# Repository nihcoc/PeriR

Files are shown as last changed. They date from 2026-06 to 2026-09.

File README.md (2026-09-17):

# PeriR
> Under Development!

---

## Abstract

A custom Software Defined Radio (SDR) HAT built around the Xilinx Artix-7 XC7A50T FPGA and Analog Devices AD9364 RF transceiver.
This project is inspired by the [FreeSRP](http://electronics.kitchen/misc/freesrp/) open-source SDR by Lukas Lao Beyer and design references from the  <a href="https://wiki.analog.com/resources/eval/user-guides/ad-fmcomms4-ebz">FMCOMMS4</a>.

The goal is a powerful, Linux-capable SDR transceiver with a compact form factor and eventually, a handheld device like the HackRF Portapack.

---

## Key Specifications

| Feature | Detail |
|---|---|
| **SoM** | Compute Module 4 |
| **FPGA** | Xilinx Artix-7 XC7A50T FPGA |
| **RF Transceiver** | Analog Devices AD9364 |
| **Frequency Range** | 70 MHz – 6.0 GHz |
| **Bandwidth** | 200 kHz – 56 MHz |
| **Interfaces** | PCIe 2.0 x1, USB2.0 |
---

## Hardware Design

Read my <a href="https://github.com/nihcoc/PeriR/blob/main/perir-journal.md">Hardware Journal and 120 Hours of footage of my entire design process</a> here!

### RF
- **Balun:** TCM1-63AX+ wideband RF transformer (10MHz to 6GHz)
- **Clock:** 40 MHz TCXO
- **Power:** ADP1754ACPZ-1.3-R7 (Recommended by AD)
- **TX Power Amp:** PGA-102 (dedicated clean 3.3V supply)
- **Trace:** Output traces are 50Ω controlled for the JLC06161H-3313A stack-up, Co-planar and no solder mask

### Power Architecture

| Rail | IC | Current | 
|---|---|---|
| 1.0V | TPS62130A | 3A | 
| 1.8V | TPS62130A | 3A | 
| 3.3V | TPS62130A | 3A | 
| 2.5V | TPS62130A | 3A | 
| 1.2V | TPS62130A | 3A | 
| 1.3V | ADP1754ACPZ-1.3-R7 | 3A |
| 5V | External connector | ~ 8A  |

> Sequencing is managed using EN (Enable) and PG (Power Good) pins chained between power ICs. See Pg8 on ([DS181](https://docs.amd.com/v/u/en-US/ds181_Artix_7_Data_Sheet))

### Interfaces
**CM4 INTERFACES**
| CM4 Interface | Notes |
|---|---|
| **HDMI** | Length matched, 100Ω  Differential|
| **USB** | Length matched, 100Ω  Differential|
| **DSI** | Length matched, 100Ω  Differential |
| **SD Card** |  Length matched, 50Ω |
| **PCIe 2.0 x1** | ±1ps Length matched , 90Ω Differential (See ([Pg7 2.3](https://pip-assets.raspberrypi.com/categories/634-raspberry-pi-compute-module-4/documents/RP-008168-DS-4-cm4-datasheet.pdf)) ) |
| **DEBUG LEDS** | Blue leds for debug/status |

> Impedance controlled according to the JLC06161H-3313A stack-up using the [JLCPCB impedence calculator](https://jlcpcb.com/pcb-impedance-calculator)

**FPGA INTERFACES**
| FPGA Interface | Notes |
|---|---|
| **USB 2.0** | Routed for the asynchronous 245 FIFO mode on FT2232HL |
| **PCIe 2.0 x1** | GTP transceivers are only supported on a few Artix-7 chips such as the CSG-325 |
| **JTAG** | Bank_0 |
| **Transceiver Digital Interface** | Routing configured for the DUAL PORT FULL DUPLEX MODE using the LVDS signaling standard. LVDS mode is supported on the XC7A50T-CSG325 but only when VCCO_x is supplied with 2.5V|
| **DEBUG LEDS** | Blue leds for debug/status |

> Impedance for the layer 3 LVDS signals is not 100Ω because I mistakenly used the JLC06161H-3313E stackup to calculate the impedance for this layer. It's not ideal, but the traces are only around 3 cm long, so the impact of the mismatch should be relatively small. I can validate the interface at a lower data rate and use diagnostics and timing analysis to check the signal margin. I'll fix the impedance mismatch properly in V2.

---

###  Key Datasheets

| Part | Source |
|---|---|
| **XC7A50T** | [UG470 CONFIG/FLASH](https://docs.amd.com/v/u/en-US/ug470_7Series_Config) |
| **XC7A50T** | [DS181 POWER](https://docs.amd.com/v/u/en-US/ds181_Artix_7_Data_Sheet) |
| **XC7A50T** | [UG483 LAYOUT/CAPS](https://docs.amd.com/v/u/en-US/ug483_7Series_PCB) |
| **XC7A50T** | [UG482 GTP(PCIe)](https://docs.amd.com/v/u/en-US/ug482_7Series_GTP_Transceivers) |
| **XC7A50T** | [UG472 CLOCKING ](https://docs.amd.com/v/u/en-US/ug472_7Series_Clocking) |
| **AD9364** | [UG673 Main Reference](https://www.analog.com/media/en/technical-documentation/data-sheets/AD9364.pdf) |
| **AD9364** | [Overview](https://www.scribd.com/document/271013063/AD9364-Reference-Manual-UG-673) |
| **FT2232H** | [Main Reference](https://ftdichip.com/wp-content/uploads/2024/09/DS_FT2232H.pdf) |
| **Compute Module 4** | [Main Reference](https://pip-assets.raspberrypi.com/categories/634-raspberry-pi-compute-module-4/documents/RP-008168-DS-4-cm4-datasheet.pdf)|
| **TPS62130** | [Main Reference](https://www.ti.com/lit/gpn/TPS62130A)|
| **ADP1754ACPZ-1.3-R7** | [Main Reference](https://www.analog.com/media/en/technical-documentation/data-sheets/ADP1754_1755.pdf)|
| **NCP700BSN33T1G** | [Main Reference](https://www.onsemi.com/pdf/datasheet/ncp700b-d.pdf)|
| **ADM7160AUJZ-1.8-R7** | [Main Reference](https://www.analog.com/media/en/technical-documentation/data-sheets/ADM7160.pdf)|
| **TCM1-63AX+** | [Main Reference](https://www.minicircuits.com/pdfs/TCM1-63AX+.pdf)|
| **PGA-102+** | [Main Reference](https://www.minicircuits.com/pdfs/PGA-102+.pdf)|

---

## Software

CM4 - FPGA - AD9364 software/digital design interface is in development.

**General Software**

- **OS:** [Kuiper Linux](https://wiki.analog.com/resources/tools-software/linux-software/kuiper-linux) by Analog Devices
- **Reference HDL:** ([https://github.com/analogdevicesinc/hdl/blob/main/library/axi_ad9361/axi_ad9361.v](https://github.com/analogdevicesinc/hdl/blob/main/library/axi_ad9361/axi_ad9361.v))

---

## Layers



*Layer 1(Top)*



*Layer 2(GND)*



*Layer 3*



*Layer 4(Power)*
> IDK how I didn't notice but my power planes look hideous and probably subpar with those sharp edges and uneven clearances. Gotta fix this in V2.



*Layer 5(GND/LOW Speed Signals)*



*Layer 6(Bottom)*

---

## Bill of Materials

 Total = ~$485(excl. shipping)

| # | LCSC# | MPN | Manufacturer | Package | Board Ref | Description | Qty | MOQ | Unit Price ($) | Ext. Price ($) | Product Link |
|---|---|-----|---|---|---|---|-----|-----|---|---|---|
| 1 | C444946 | AD9364BBCZ | ADI | BGA-144 | U4 | -122dBm 70MHz~6GHz 1.2V~3.3V BGA-144 RF Transceiver ICs RoHS | 1 | 1 | 96.5166 | 96.52 | [Link](https://www.lcsc.com/product-detail/C444946.html) |
| 2 | C5199907 | SMA-J-P-H-ST-EM1 | Samtec | SMD | J12, J13, J14 | Connector Receptacle SMA 50Ω | 3 | 1 | 4.8959 | 14.69 | [Link](https://www.lcsc.com/product-detail/C5199907.html) |
| 3 | C337502 | TPS62130ARGTR | TI | QFN-16-EP(3x3) | U7, U8, U9, U10, U12 | 2.5MHz Step-down type Adjustable 900mV~6V 3A QFN-16-EP(3x3) Voltage Regulators - DC DC Switching Regulators RoHS | 5 | 1 | 0.7910 | 3.96 | [Link](https://www.lcsc.com/product-detail/C337502.html) |
| 4 | C9002 | X322512MSB4SI | YXC Crystal Oscillators | SMD3225-4P | Y4 | Crystal 12MHz ±10ppm 20pF SMD3225-4P | 5 | 5 | 0.1012 | 0.51 | [Link](https://www.lcsc.com/product-detail/C9002.html) |
| 5 | C55061480 | PUBFA-R23A-003 | YUWENFA | Through Hole | J7 | USB 2.0 Through Hole USB, DVI, HDMI Connector Adapters RoHS | 5 | 5 | 0.0583 | 0.29 | [Link](https://www.lcsc.com/product-detail/C55061480.html) |
| 6 | C720616 | HDMI-001S | XUNPU | SMD | J5 | HDMI-A Receptacle Connector 19 Position Surface Mount, Right Angle | 5 | 5 | 0.2424 | 1.21 | [Link](https://www.lcsc.com/product-detail/C720616.html) |
| 7 | C2765186 | TYPE-C 16PIN 2MD(073) | SHOU HAN | SMD | J9 | USB-C (USB TYPE-C) Receptacle Connector 16 Position Surface Mount, Right Angle | 20 | 20 | 0.0707 | 1.41 | [Link](https://www.lcsc.com/product-detail/C2765186.html) |
| 8 | C7529389 | TF-CARD H1.8 | SHOU HAN | SMD | J2 | Micro SD card (TF card) Connector and Ejector Push-Push Surface Mount | 10 | 10 | 0.0608 | 0.61 | [Link](https://www.lcsc.com/product-detail/C7529389.html) |
| 9 | C720557 | DC-005-A200 | XUNPU | Through Hole | J10 | Power Barrel Connector Jack 2mm ID 6.4mm OD Through Hole, Right Angle | 5 | 5 | 0.1294 | 0.65 | [Link](https://www.lcsc.com/product-detail/C720557.html) |
| 10 | C502010 | MLJ1608WR33JT000 | TDK | 0603 | L13, L14 | 500mA 330nH ±5% 320mΩ 650mA Multilayer inductor 0603 Fixed Inductors RoHS | 10 | 10 | 0.0744 | 0.74 | [Link](https://www.lcsc.com/product-detail/C502010.html) |
| 11 | C85837 | BLM21AG601SN1D | muRata | 0805 | FB4 | 600Ω@100MHz 1 Line Ferrite Bead 0805 700mA 210mΩ | 20 | 20 | 0.0618 | 1.24 | [Link](https://www.lcsc.com/product-detail/C85837.html) |
| 12 | C424649 | DF40HC(3.0)-100DS-0.4V(51) | HRS | SMD, P=0.4mm | H1 | High-Density Board-to-Board Connector 100-pos 0.4mm pitch | 2 | 1 | 1.8918 | 3.78 | [Link](https://www.lcsc.com/product-detail/C424649.html) |
| 13 | C25120 | 0402WGF499JTCE | UNI-ROYAL | 0402 | R33 | 49.9Ω ±1% 62.5mW 0402 Thick Film Resistor | 100 | 100 | 0.0011 | 0.11 | [Link](https://www.lcsc.com/product-detail/C25120.html) |
| 14 | C2906901 | FRC0402J1R0 TS | FOJAN | 0402 | R31, R32 | 1Ω ±5% 62.5mW 0402 Thick Film Resistor | 100 | 100 | 0.0016 | 0.16 | [Link](https://www.lcsc.com/product-detail/C2906901.html) |
| 15 | C852856 | RT0402BRD075K1L | YAGEO | 0402 | R27, R28 | 5.1kΩ 62.5mW 50V Thin Film Resistor ±25ppm/℃ ±0.1% 0402 Chip Resistor - Surface Mount RoHS | 50 | 50 | 0.0216 | 1.08 | [Link](https://www.lcsc.com/product-detail/C852856.html) |
| 16 | C2909316 | FRC0402F1202TS | FOJAN | 0402 | R25 | 12kΩ ±1% 62.5mW 0402 Thick Film Resistor | 100 | 100 | 0.0014 | 0.14 | [Link](https://www.lcsc.com/product-detail/C2909316.html) |
| 17 | C190095 | RT0402BRD0710KL | YAGEO | 0402 | R19, R20, R24, R30, R35 | 62.5mW 10kΩ 50V Thin Film Resistor ±25ppm/℃ ±0.1% 0402 Chip Resistor - Surface Mount RoHS | 50 | 50 | 0.0207 | 1.04 | [Link](https://www.lcsc.com/product-detail/C190095.html) |
| 18 | C2906865 | FRC0402F2201TS | FOJAN | 0402 | R17, R18 | 2.2kΩ ±1% 62.5mW 0402 Thick Film Resistor | 100 | 100 | 0.0016 | 0.16 | [Link](https://www.lcsc.com/product-detail/C2906865.html) |
| 19 | C106232 | RC0402FR-07100RL | YAGEO | 0402 | R8 | 100Ω 62.5mW 50V Thick Film Resistor ±100ppm/℃ ±1% 0402 Chip Resistor - Surface Mount RoHS | 100 | 100 | 0.0013 | 0.13 | [Link](https://www.lcsc.com/product-detail/C106232.html) |
| 20 | C242160 | ERJ2GE0R00X | PANASONIC | 0402 | R7 | 100mW 0Ω Thick Film Resistor -100ppm/℃~+600ppm/℃ 0402 Chip Resistor - Surface Mount RoHS | 100 | 100 | 0.0047 | 0.47 | [Link](https://www.lcsc.com/product-detail/C242160.html) |
| 21 | C71626 | CRCW0402330RFKED | VISHAY | 0402 | R5 | 63mW 330Ω Thick Film Resistor ±100ppm/℃ ±1% 0402 Chip Resistor - Surface Mount RoHS | 100 | 100 | 0.0037 | 0.37 | [Link](https://www.lcsc.com/product-detail/C71626.html) |
| 22 | C1884625 | MCS04020C4701FE000 | VISHAY | 0402 | R2, R3, R29 | 100mW 4.7kΩ 50V Thin Film Resistor ±50ppm/℃ ±1% 0402 Chip Resistor - Surface Mount RoHS | 20 | 20 | 0.0304 | 0.61 | [Link](https://www.lcsc.com/product-detail/C1884625.html) |
| 23 | C852624 | RT0402BRD071KL | YAGEO | 0402 | R1, R2(DNP), R3(DNP), R4, R5(DNP), R6, R26 | 1kΩ 62.5mW 50V Thin Film Resistor ±25ppm/℃ ±0.1% 0402 Chip Resistor - Surface Mount RoHS | 50 | 50 | 0.0199 | 1.00 | [Link](https://www.lcsc.com/product-detail/C852624.html) |
| 24 | C5633358 | ECS-TXO-32CSMV-400-BN-TR | ECS | SMD3225-4P | Y6 | 40MHz SMD3225-4P Oscillators RoHS | 1 | 1 | 2.6285 | 2.63 | [Link](https://www.lcsc.com/product-detail/C5633358.html) |
| 25 | C7522691 | LQW18AS43NJ00D | muRata | 0603 | L11 | 600mA 43nH ±5% 280mΩ Wire-wound chip inductor 0603 Fixed Inductors RoHS | 5 | 5 | 0.0895 | 0.45 | [Link](https://www.lcsc.com/product-detail/C7522691.html) |
| 26 | C51048295 | FRC0402F1432TS | FOJAN | 0402 | R34 | 62.5mW 14.3kΩ 50V Thick Film Resistor ±1% 0402 Chip Resistor - Surface Mount RoHS | 100 | 100 | 0.0008 | 0.08 | [Link](https://www.lcsc.com/product-detail/C51048295.html) |
| 27 | C2906952 | FRC0402J513 TS | FOJAN | 0402 | R84 | 51kΩ ±5% 62.5mW 0402 Thick Film Resistor | 100 | 100 | 0.0013 | 0.13 | [Link](https://www.lcsc.com/product-detail/C2906952.html) |
| 28 | C144785 | AC0402FR-07200KL | YAGEO | 0402 | R85, R125 | 62.5mW 200kΩ 50V Thick Film Resistor ±100ppm/℃ ±1% 0402 Chip Resistor - Surface Mount RoHS | 100 | 100 | 0.0018 | 0.18 | [Link](https://www.lcsc.com/product-detail/C144785.html) |
| 29 | C481918 | CRCW0402100KFKED | VISHAY | 0402 | R86, R87, R88, R89, R91, R127, R129, R133 | 100kΩ 63mW 50V Thick Film Resistor ±1% ±100ppm/℃ 0402 Chip Resistor - Surface Mount RoHS | 100 | 100 | 0.0038 | 0.38 | [Link](https://www.lcsc.com/product-detail/C481918.html) |
| 30 | C7467320 | FRC0402J164 TS | FOJAN | 0402 | R126 | 62.5mW 160kΩ 50V Thick Film Resistor ±5% ±100ppm/℃ 0402 Chip Resistor - Surface Mount RoHS | 100 | 100 | 0.0011 | 0.11 | [Link](https://www.lcsc.com/product-detail/C7467320.html) |
| 31 | C2906873 | FRC0402F4992TS | FOJAN | 0402 | R128 | 49.9kΩ ±1% 62.5mW 0402 Thick Film Resistor | 100 | 100 | 0.0015 | 0.15 | [Link](https://www.lcsc.com/product-detail/C2906873.html) |
| 32 | C2515044 | RN73H1ETTP2133D25 | KOA | 0402 | R130 | 62.5mW 213kΩ Metal Film Resistor ±0.5% ±25ppm/℃ 0402 Chip Resistor - Surface Mount RoHS | 1 | 1 | 0.0568 | 0.06 | [Link](https://www.lcsc.com/product-detail/C2515044.html) |
| 33 | C4180598 | RE0402BRE07309KL | YAGEO | 0402 | R134 | 309kΩ 62.5mW Thick Film Resistor ±50ppm/℃ ±0.1% 0402 Chip Resistor - Surface Mount RoHS | 20 | 20 | 0.0111 | 0.22 | [Link](https://www.lcsc.com/product-detail/C4180598.html) |
| 34 | C494678 | TCM1-63AX+ | Mini-Circuits | SMD-6P | T4, T6 | 9.42dB 8° 10MHz~6GHz 2.5dB 50Ω:50Ω SMD-6P Balun RoHS | 2 | 1 | 17.6099 | 35.22 | [Link](https://www.lcsc.com/product-detail/C494678.html) |
| 35 | C1521759 | XC7A50T-2CSG325I | AMD/XILINX | FPGA-325(15x15) | U2 | 52160 FPGA-325(15x15) FPGAs (Field Programmable Gate Array) RoHS | 1 | 1 | 52.4575 | 52.46 | [Link](https://www.lcsc.com/product-detail/C1521759.html) |
| 36 | C27882 | FT2232HL-REEL | FTDI | LQFP-64(10x10) | U3 | 480Mbps USB 2.0 LQFP-64(10x10) Interface Controllers RoHS | 1 | 1 | 12.4162 | 12.42 | [Link](https://www.lcsc.com/product-detail/C27882.html) |
| 37 | C3193264 | PGA-102+ | Mini-Circuits | SOT-89 | U11 | 10.4dB 50MHz~6GHz 3.1V~3.5V 3.9dB 17.5dBm 83mA SOT-89 RF Amplifiers RoHS | 1 | 1 | 2.3356 | 2.34 | [Link](https://www.lcsc.com/product-detail/C3193264.html) |
| 38 | C1997058 | SG-8018CA 100.0000M-TJHSA0 | EPSON | SMD7050-4P | Y2 | 100MHz SMD7050-4P Oscillators RoHS | 1 | 1 | 1.0742 | 1.07 | [Link](https://www.lcsc.com/product-detail/C1997058.html) |
| 39 | C76941 | GRM033R71A103KA01D | muRata | 0201 | C284, C292, C305 | 10nF ±10% 10V Ceramic Capacitor X7R 0201 | 100 | 100 | 0.0050 | 0.50 | [Link](https://www.lcsc.com/product-detail/C76941.html) |
| 40 | C368809 | CL05A475KP5NRNC | Samsung Electro-Mechanics | 0402 | C1, C2, C9, C12, C13, C18, C19, C24, C25, C30, C31, C46, C85, C86, C313 | 4.7uF ±10% 10V Ceramic Capacitor X5R 0402 | 50 | 50 | 0.0116 | 0.58 | [Link](https://www.lcsc.com/product-detail/C368809.html) |
| 41 | C6663208 | 298W107X0004M2T | VISHAY | 0603 | C3, C14 | 100uF ±20% 4V Tantalum Capacitors 0603 | 2 | 1 | 1.8719 | 3.74 | [Link](https://www.lcsc.com/product-detail/C6663208.html) |
| 42 | C92361 | CL05A474KA5NNNC | Samsung Electro-Mechanics | 0402 | C4, C5, C6, C11, C15, C16, C17, C20, C21, C22, C23, C26, C27, C28, C29, C32, C33, C34, C35 | 470nF ±10% 25V Ceramic Capacitor X5R 0402 | 20 | 10 | 0.0163 | 0.33 | [Link](https://www.lcsc.com/product-detail/C92361.html) |
| 43 | C60474 | CC0402KRX7R7BB104 | YAGEO | 0402 | C267, C271, C277, C287, C289, C291, C295, C296, C310, C320 | 100nF ±10% 16V Ceramic Capacitor X7R 0402 | 200 | 100 | 0.0072 | 1.44 | [Link](https://www.lcsc.com/product-detail/C60474.html) |
| 44 | C140782 | GRM188R60J476ME15D | muRata | 0603 | C10, C42, C43, C265, C269, C274, C281, C285, C288, C290, C293, C308 | 47uF ±20% 6.3V Ceramic Capacitor X5R 0603 | 20 | 10 | 0.1431 | 2.86 | [Link](https://www.lcsc.com/product-detail/C140782.html) |
| 45 | C51412 | CL10A335KP8NNNC | Samsung Electro-Mechanics | 0603 | C77 | 3.3uF ±10% 10V Ceramic Capacitor X5R 0603 | 10 | 10 | 0.0311 | 0.31 | [Link](https://www.lcsc.com/product-detail/C51412.html) |
| 46 | C384976 | GRM0335C1H270GA01D | muRata | 0201 | C89, C90 | 27pF ±2% 50V Ceramic Capacitor C0G 0201 | 100 | 100 | 0.0048 | 0.48 | [Link](https://www.lcsc.com/product-detail/C384976.html) |
| 47 | C29266 | CL05A105KO5NNNC | Samsung Electro-Mechanics | 0402 | C91, C97, C304, C306, C307, C314 | 1uF ±10% 16V Ceramic Capacitor X5R 0402 | 100 | 100 | 0.0072 | 0.72 | [Link](https://www.lcsc.com/product-detail/C29266.html) |
| 48 | C307380 | CL03A104KO3NNNC | Samsung Electro-Mechanics | 0201 | C99, C100, C101, C102, C103, C105, C106, C107, C108, C109, C111, C112, C113, C115, C117, C118, C119, C312 | 100nF ±10% 16V Ceramic Capacitor X5R 0201 | 200 | 100 | 0.0029 | 0.58 | [Link](https://www.lcsc.com/product-detail/C307380.html) |
| 49 | C19702 | CL10A106KP8NNNC | Samsung Electro-Mechanics | 0603 | C104, C110, C114, C116, C266, C270, C275, C283, C286, C294, C309, C321 | 10uF ±10% 10V Ceramic Capacitor X5R 0603 | 20 | 20 | 0.0822 | 1.64 | [Link](https://www.lcsc.com/product-detail/C19702.html) |
| 50 | C62164 | 0201CG180J500NT | FH | 0201 | C120, C121, C317, C318 | 18pF ±5% 50V Ceramic Capacitor C0G 0201 | 100 | 100 | 0.0029 | 0.29 | [Link](https://www.lcsc.com/product-detail/C62164.html) |
| 51 | C161488 | GRM033R71E222KA12D | muRata | 0201 | C262, C264, C272, C280, C303 | 2.2nF ±10% 25V Ceramic Capacitor X7R 0201 | 100 | 100 | 0.0052 | 0.52 | [Link](https://www.lcsc.com/product-detail/C161488.html) |
| 52 | C86295 | CL10A226MP8NUNE | Samsung Electro-Mechanics | 0603 | C263, C268, C278, C297 | 22uF ±20% 10V Ceramic Capacitor X5R 0603 | 10 | 10 | 0.0380 | 0.38 | [Link](https://www.lcsc.com/product-detail/C86295.html) |
| 53 | C122469 | XFL4020-222MEC | Coilcraft | SMD, 4x4mm | L7, L8, L9, L10, L12 | 8A 2.2uH ±20% 21.35mΩ 3.7A SMD 4x4mm Fixed Inductors RoHS | 5 | 1 | 1.3566 | 6.78 | [Link](https://www.lcsc.com/product-detail/C122469.html) |
| 54 | C602037 | CL21A226MAYNNNE | Samsung Electro-Mechanics | 0805 | C311 | 22uF ±20% 25V Ceramic Capacitor X5R 0805 | 10 | 10 | 0.1135 | 1.14 | [Link](https://www.lcsc.com/product-detail/C602037.html) |
| 55 | C17291088 | GCM033R71A122KA03D | muRata | 0201 | C315 | 1.2nF X7R ±10% 10V 0201 Ceramic Capacitors RoHS | 100 | 100 | 0.0094 | 0.94 | [Link](https://www.lcsc.com/product-detail/C17291088.html) |
| 56 | C88914 | GRM0335C1H680JA01D | muRata | 0201 | C316 | 68pF ±5% 50V Ceramic Capacitor C0G 0201 | 100 | 100 | 0.0017 | 0.17 | [Link](https://www.lcsc.com/product-detail/C88914.html) |
| 57 | C505464 | CC0201KRX7R9BB102 | YAGEO | 0201 | C319 | 1nF ±10% 50V Ceramic Capacitor X7R 0201 | 100 | 100 | 0.0018 | 0.18 | [Link](https://www.lcsc.com/product-detail/C505464.html) |
| 58 | C133346 | ESD8472MUT5G | onsemi | X3-DFN-2(0.3x0.6) | D5, D12 | 15V Clamp 20V Clamp 3A@8/20us Ipp ESD DIODE X3-DFN-2(0.3x0.6) | 5 | 5 | 0.0826 | 0.41 | [Link](https://www.lcsc.com/product-detail/C133346.html) |
| 59 | C598848 | MT25QU128ABA8ESF-0SIT | Micron | SOIC-16-300mil | IC1 | SOIC-16-300mil NOR Flash Memory RoHS | 1 | 1 | 10.2374 | 10.24 | [Link](https://www.lcsc.com/product-detail/C598848.html) |
| 60 | C613841 | 93C46B/P | MICROCHIP | PDIP-8 | IC3 | 1Kbit 4.5V~5.5V 2MHz SPI PDIP-8 Memory (ICs) RoHS | 1 | 1 | 1.0827 | 1.08 | [Link](https://www.lcsc.com/product-detail/C613841.html) |
| 61 | C3747719 | ADP1754ACPZ-1.3-R7 | ADI | LFCSP-16(4x4) | IC10, IC11 | 1.3V Positive Fixed LFCSP-16(4x4) Voltage Regulators - Linear, Low Drop Out (LDO) Regulators RoHS | 2 | 1 | 4.6333 | 9.27 | [Link](https://www.lcsc.com/product-detail/C3747719.html) |
| 62 | C892685 | NCP700BSN33T1G | onsemi | TSOP-5-1.5mm | IC13 | 3.3V Positive Fixed TSOP-5-1.5mm Voltage Regulators - Linear, Low Drop Out (LDO) Regulators RoHS | 1 | 1 | 1.2691 | 1.27 | [Link](https://www.lcsc.com/product-detail/C892685.html) |
| 63 | C658468 | ADM7160AUJZ-1.8-R7 | ADI | TSOT-5 | IC14 | Linear Voltage Regulator IC Positive Fixed 1 Output 200mA TSOT-5 | 1 | 1 | 2.7671 | 2.77 | [Link](https://www.lcsc.com/product-detail/C658468.html) |
| 64 | C5410688 | 69145-210LF | Amphenol | — | J1 | Open-Top 2.54mm Shunts, Jumpers RoHS | 1 | 1 | 1.0308 | 1.03 | [Link](https://www.lcsc.com/product-detail/C5410688.html) |
| 65 | C3168185 | FH19SC-22S-0.5SH(09) | HRS | SMD, P=0.5mm | J6 | FFC/FPC Connector 22 Position 0.5mm Pitch Bottom Contact Surface Mount, Right Angle | 1 | 1 | 1.7125 | 1.71 | [Link](https://www.lcsc.com/product-detail/C3168185.html) |
| 66 | --- | Compute Module 4 CM4101000 WIFI Lite | RPi | --- | --- | --- | 1 | 1 | 95 | 95 | [Link](https://ar.aliexpress.com/item/1005008557413104.html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) |
| 67 | --- | PCBA | JLCPCB | --- | --- | 6 - Layer | 1 | 1 | 100 | 100 | --- |

Fallout Zine
---
*Special Thanks to Hack Club and the fabulous people at Fallout 2026!*

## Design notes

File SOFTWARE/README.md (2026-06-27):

# PeriR — Barebones Bringup Code

## Structure

```
perir/
├── fpga/
│   ├── loopback_reg.v        # Phase 1: AXI register loopback (no AD9364)
│   └── ad9364_spi_bringup.v  # Phase 2: SPI chip ID read
├── cm4/
│   ├── cm4_xdma_test.py      # Phase 3: PCIe + BAR0 register test from CM4
│   └── integration_test.py   # Phase 5: End-to-end IQ streaming test
└── gnuradio/
    └── perir_source.py       # Phase 4+: GNU Radio source block
```

## Build Order

| Phase | File | What it proves |
|---|---|---|
| 1 | `loopback_reg.v` + `cm4_xdma_test.py` | PCIe link up, AXI R/W works |
| 2 | `ad9364_spi_bringup.v` + `cm4_xdma_test.py` | AD9364 alive on SPI |
| 3 | `integration_test.py` | IQ samples flowing end-to-end |
| 4 | `perir_source.py` | GNU Radio can receive IQ |

## FPGA Setup

1. Build ADI HDL library (`axi_ad9361`, `axi_dmac`)
2. Create Vivado project targeting `xc7a50tcsg325`
3. Add `loopback_reg.v` as top module for Phase 1
4. Add `ad9364_spi_bringup.v` for Phase 2
5. Gradually replace with `perir_top.v` (full design)

## CM4 Setup (Kuiper Linux)

```bash
# Load XDMA driver
sudo modprobe xdma

# Verify PCIe
lspci

# Run tests
sudo python3 cm4/cm4_xdma_test.py
sudo python3 cm4/integration_test.py
```

## Notes

- All register offsets in CM4 code must match FPGA design exactly
- Run CM4 scripts with `sudo` (XDMA devices need root by default)
- Add udev rules later to avoid sudo requirement

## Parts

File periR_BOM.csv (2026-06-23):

Index | LCSC# | MPN | Manufacturer | Package | Board Ref | Description | Quantity | MOQ | Unit Price($) | Extended Price($) | Product Link
1 | C444946 | AD9364BBCZ | ADI | BGA-144 | U4 | -122dBm 70MHz~6GHz 1.2V~3.3V BGA-144 RF Transceiver ICs RoHS | 1 | 1 | 96.5166 | 96.52 | https://www.lcsc.com/product-detail/C444946.html
2 | C5199907 | SMA-J-P-H-ST-EM1 | Samtec | SMD | J12,J13,J14 | Connector Receptacle SMA 50Ω | 3 | 1 | 4.8959 | 14.69 | https://www.lcsc.com/product-detail/C5199907.html
3 | C337502 | TPS62130ARGTR | TI | QFN-16-EP(3x3) | U7,U8,U9,U10,U12 | 2.5MHz Step-down type Adjustable 900mV~6V 3A QFN-16-EP(3x3) Voltage Regulators - DC DC Switching Regulators RoHS | 5 | 1 | 0.791 | 3.96 | https://www.lcsc.com/product-detail/C337502.html
4 | C9002 | X322512MSB4SI | YXC Crystal Oscillators | SMD3225-4P | Y4 | Crystal 12MHz ±10ppm 20pF SMD3225-4P | 5 | 5 | 0.1012 | 0.51 | https://www.lcsc.com/product-detail/C9002.html
5 | C55061480 | PUBFA-R23A-003 | YUWENFA | Through Hole | J7 | USB 2.0 Through Hole USB, DVI, HDMI Connector Adapters RoHS | 5 | 5 | 0.0583 | 0.29 | https://www.lcsc.com/product-detail/C55061480.html
6 | C720616 | HDMI-001S | XUNPU | SMD | J5 | HDMI-A Receptacle Connector 19 Position Surface Mount, Right Angle | 5 | 5 | 0.2424 | 1.21 | https://www.lcsc.com/product-detail/C720616.html
7 | C2765186 | TYPE-C 16PIN 2MD(073) | SHOU HAN | SMD | J9 | USB-C (USB TYPE-C) Receptacle Connector 16 Position Surface Mount, Right Angle | 20 | 20 | 0.0707 | 1.41 | https://www.lcsc.com/product-detail/C2765186.html
8 | C7529389 | TF-CARD H1.8 | SHOU HAN | SMD | J2 | Micro SD card (TF card) Connector and Ejector Push-Push Surface Mount | 10 | 10 | 0.0608 | 0.61 | https://www.lcsc.com/product-detail/C7529389.html
9 | C720557 | DC-005-A200 | XUNPU | Through Hole | J10 | Power Barrel Connector Jack 2mm ID 6.4mm OD Through Hole, Right Angle | 5 | 5 | 0.1294 | 0.65 | https://www.lcsc.com/product-detail/C720557.html
10 | C502010 | MLJ1608WR33JT000 | TDK | 603 | L13,L14 | 500mA 330nH ±5% 320mΩ 650mA Multilayer inductor 0603 Fixed Inductors RoHS | 10 | 10 | 0.0744 | 0.74 | https://www.lcsc.com/product-detail/C502010.html
11 | C85837 | BLM21AG601SN1D | muRata | 805 | FB4 | 600Ω@100MHz 1 Line Ferrite Bead 0805 700mA 210mΩ | 20 | 20 | 0.0618 | 1.24 | https://www.lcsc.com/product-detail/C85837.html
12 | C424649 | DF40HC(3.0)-100DS-0.4V(51) | HRS | SMD,P=0.4mm | H1 | nan | 2 | 1 | 1.8918 | 3.78 | https://www.lcsc.com/product-detail/C424649.html
13 | C25120 | 0402WGF499JTCE | UNI-ROYAL | 402 | R33 | 49.9Ω ±1% 62.5mW 0402 Thick Film Resistor | 100 | 100 | 0.0011 | 0.11 | https://www.lcsc.com/product-detail/C25120.html
14 | C2906901 | FRC0402J1R0 TS | FOJAN | 402 | R31,R32 | 1Ω ±5% 62.5mW 0402 Thick Film Resistor | 100 | 100 | 0.0016 | 0.16 | https://www.lcsc.com/product-detail/C2906901.html
15 | C852856 | RT0402BRD075K1L | YAGEO | 402 | R27,R28 | 5.1kΩ 62.5mW 50V Thin Film Resistor ±25ppm/℃ ±0.1% 0402 Chip Resistor - Surface Mount RoHS | 50 | 50 | 0.0216 | 1.08 | https://www.lcsc.com/product-detail/C852856.html
16 | C2909316 | FRC0402F1202TS | FOJAN | 402 | R25 | 12kΩ ±1% 62.5mW 0402 Thick Film Resistor | 100 | 100 | 0.0014 | 0.14 | https://www.lcsc.com/product-detail/C2909316.html
17 | C190095 | RT0402BRD0710KL | YAGEO | 402 | R19,R20,R24,R30,R35 | 62.5mW 10kΩ 50V Thin Film Resistor ±25ppm/℃ ±0.1% 0402 Chip Resistor - Surface Mount RoHS | 50 | 50 | 0.0207 | 1.04 | https://www.lcsc.com/product-detail/C190095.html
18 | C2906865 | FRC0402F2201TS | FOJAN | 402 | R17,R18 | 2.2kΩ ±1% 62.5mW 0402 Thick Film Resistor | 100 | 100 | 0.0016 | 0.16 | https://www.lcsc.com/product-detail/C2906865.html
19 | C106232 | RC0402FR-07100RL | YAGEO | 402 | R8 | 100Ω 62.5mW 50V Thick Film Resistor ±100ppm/℃ ±1% 0402 Chip Resistor - Surface Mount RoHS | 100 | 100 | 0.0013 | 0.13 | https://www.lcsc.com/product-detail/C106232.html
20 | C242160 | ERJ2GE0R00X | PANASONIC | 402 | R7 | 100mW 0Ω Thick Film Resistor -100ppm/℃~+600ppm/℃ 0402 Chip Resistor - Surface Mount RoHS | 100 | 100 | 0.0047 | 0.47 | https://www.lcsc.com/product-detail/C242160.html
21 | C71626 | CRCW0402330RFKED | VISHAY | 402 | R5 | 63mW 330Ω Thick Film Resistor ±100ppm/℃ ±1% 0402 Chip Resistor - Surface Mount RoHS | 100 | 100 | 0.0037 | 0.37 | https://www.lcsc.com/product-detail/C71626.html
22 | C1884625 | MCS04020C4701FE000 | VISHAY | 402 | R2,R3,R29 | 100mW 4.7kΩ 50V Thin Film Resistor ±50ppm/℃ ±1% 0402 Chip Resistor - Surface Mount RoHS | 20 | 20 | 0.0304 | 0.61 | https://www.lcsc.com/product-detail/C1884625.html
23 | C852624 | RT0402BRD071KL | YAGEO | 402 | R1,R2(DNP)1,R3(DNP)1,R4,R5(DNP)1,R6,R26 | 1kΩ 62.5mW 50V Thin Film Resistor ±25ppm/℃ ±0.1% 0402 Chip Resistor - Surface Mount RoHS | 50 | 50 | 0.0199 | 1 | https://www.lcsc.com/product-detail/C852624.html
24 | C5633358 | ECS-TXO-32CSMV-400-BN-TR | ECS | SMD3225-4P | Y6 | 40MHz SMD3225-4P Oscillators RoHS | 1 | 1 | 2.6285 | 2.63 | https://www.lcsc.com/product-detail/C5633358.html
25 | C7522691 | LQW18AS43NJ00D | muRata | 603 | L11 | 600mA 43nH ±5% 280mΩ Wire-wound chip inductor 0603 Fixed Inductors RoHS | 5 | 5 | 0.0895 | 0.45 | https://www.lcsc.com/product-detail/C7522691.html
26 | C51048295 | FRC0402F1432TS | FOJAN | 402 | R34 | 62.5mW 14.3kΩ 50V Thick Film Resistor ±1% 0402 Chip Resistor - Surface Mount RoHS | 100 | 100 | 0.0008 | 0.08 | https://www.lcsc.com/product-detail/C51048295.html
27 | C2906952 | FRC0402J513 TS | FOJAN | 402 | R84 | 51kΩ ±5% 62.5mW 0402 Thick Film Resistor | 100 | 100 | 0.0013 | 0.13 | https://www.lcsc.com/product-detail/C2906952.html
28 | C144785 | AC0402FR-07200KL | YAGEO | 402 | R85,R125 | 62.5mW 200kΩ 50V Thick Film Resistor ±100ppm/℃ ±1% 0402 Chip Resistor - Surface Mount RoHS | 100 | 100 | 0.0018 | 0.18 | https://www.lcsc.com/product-detail/C144785.html
29 | C481918 | CRCW0402100KFKED | VISHAY | 402 | R86,R87,R88,R89,R91,R127,R129,R133 | 100kΩ 63mW 50V Thick Film Resistor ±1% ±100ppm/℃ 0402 Chip Resistor - Surface Mount RoHS | 100 | 100 | 0.0038 | 0.38 | https://www.lcsc.com/product-detail/C481918.html
30 | C7467320 | FRC0402J164 TS | FOJAN | 402 | R126 | 62.5mW 160kΩ 50V Thick Film Resistor ±5% ±100ppm/℃ 0402 Chip Resistor - Surface Mount RoHS | 100 | 100 | 0.0011 | 0.11 | https://www.lcsc.com/product-detail/C7467320.html
31 | C2906873 | FRC0402F4992TS | FOJAN | 402 | R128 | 49.9kΩ ±1% 62.5mW 0402 Thick Film Resistor | 100 | 100 | 0.0015 | 0.15 | https://www.lcsc.com/product-detail/C2906873.html
32 | C2515044 | RN73H1ETTP2133D25 | KOA | 402 | R130 | 62.5mW 213kΩ Metal Film Resistor ±0.5% ±25ppm/℃ 0402 Chip Resistor - Surface Mount RoHS | 1 | 1 | 0.0568 | 0.06 | https://www.lcsc.com/product-detail/C2515044.html
33 | C4180598 | RE0402BRE07309KL | YAGEO | 402 | R134 | 309kΩ 62.5mW Thick Film Resistor ±50ppm/℃ ±0.1% 0402 Chip Resistor - Surface Mount RoHS | 20 | 20 | 0.0111 | 0.22 | https://www.lcsc.com/product-detail/C4180598.html
34 | C494678 | TCM1-63AX+ | Mini-Circuits | SMD-6P | T4,T6 | 9.42dB 8° 10MHz~6GHz 2.5dB 50Ω:50Ω SMD-6P Balun RoHS | 2 | 1 | 17.6099 | 35.22 | https://www.lcsc.com/product-detail/C494678.html
35 | C1521759 | XC7A50T-2CSG325I | AMD/XILINX | FPGA-325(15x15) | U2 | 52160 FPGA-325(15x15) FPGAs (Field Programmable Gate Array) RoHS | 1 | 1 | 52.4575 | 52.46 | https://www.lcsc.com/product-detail/C1521759.html
36 | C27882 | FT2232HL-REEL | FTDI | LQFP-64(10x10) | U3 | 480Mbps USB 2.0 LQFP-64(10x10) Interface Controllers RoHS | 1 | 1 | 12.4162 | 12.42 | https://www.lcsc.com/product-detail/C27882.html
37 | C3193264 | PGA-102+ | Mini-Circuits | SOT-89 | U11 | 10.4dB 50MHz~6GHz 3.1V~3.5V 3.9dB 17.5dBm 83mA SOT-89 RF Amplifiers RoHS | 1 | 1 | 2.3356 | 2.34 | https://www.lcsc.com/product-detail/C3193264.html
38 | C1997058 | SG-8018CA 100.0000M-TJHSA0 | EPSON | SMD7050-4P | Y2 | 100MHz SMD7050-4P Oscillators RoHS | 1 | 1 | 1.0742 | 1.07 | https://www.lcsc.com/product-detail/C1997058.html
39 | C76941 | GRM033R71A103KA01D | muRata | 201 | C284,C292,C305 | 10nF ±10% 10V Ceramic Capacitor X7R 0201 | 100 | 100 | 0.005 | 0.5 | https://www.lcsc.com/product-detail/C76941.html
40 | C368809 | CL05A475KP5NRNC | Samsung Electro-Mechanics | 402 | C1,C2,C9,C12,C13,C18,C19,C24,C25,C30,C31,C46,C85,C86,C313 | 4.7uF ±10% 10V Ceramic Capacitor X5R 0402 | 50 | 50 | 0.0116 | 0.58 | https://www.lcsc.com/product-detail/C368809.html
41 | C6663208 | 298W107X0004M2T | VISHAY | 603 | C3,C14 | 100uF ±20% 4V Tantalum Capacitors 0603 | 2 | 1 | 1.8719 | 3.74 | https://www.lcsc.com/product-detail/C6663208.html
42 | C92361 | CL05A474KA5NNNC | Samsung Electro-Mechanics | 402 | C4,C5,C6,C11,C15,C16,C17,C20,C21,C22,C23,C26,C27,C28,C29,C32,C33,C34,C35 | 470nF ±10% 25V Ceramic Capacitor X5R 0402 | 20 | 10 | 0.0163 | 0.33 | https://www.lcsc.com/product-detail/C92361.html
43 | C60474 | CC0402KRX7R7BB104 | YAGEO | 402 | C267,C271,C277,C287,C289,C291,C295,C296,C310,C320 | 100nF ±10% 16V Ceramic Capacitor X7R 0402 | 200 | 100 | 0.0072 | 1.44 | https://www.lcsc.com/product-detail/C60474.html
44 | C140782 | GRM188R60J476ME15D | muRata | 603 | C10,C42,C43,C265,C269,C274,C281,C285,C288,C290,C293,C308 | 47uF ±20% 6.3V Ceramic Capacitor X5R 0603 | 20 | 10 | 0.1431 | 2.86 | https://www.lcsc.com/product-detail/C140782.html
45 | C51412 | CL10A335KP8NNNC | Samsung Electro-Mechanics | 603 | C77 | 3.3uF ±10% 10V Ceramic Capacitor X5R 0603 | 10 | 10 | 0.0311 | 0.31 | https://www.lcsc.com/product-detail/C51412.html
46 | C384976 | GRM0335C1H270GA01D | muRata | 201 | C89,C90 | 27pF ±2% 50V Ceramic Capacitor C0G 0201 | 100 | 100 | 0.0048 | 0.48 | https://www.lcsc.com/product-detail/C384976.html
47 | C29266 | CL05A105KO5NNNC | Samsung Electro-Mechanics | 402 | C91,C97,C304,C306,C307,C314 | 1uF ±10% 16V Ceramic Capacitor X5R 0402 | 100 | 100 | 0.0072 | 0.72 | https://www.lcsc.com/product-detail/C29266.html
48 | C307380 | CL03A104KO3NNNC | Samsung Electro-Mechanics | 201 | C99,C100,C101,C102,C103,C105,C106,C107,C108,C109,C111,C112,C113,C115,C117,C118,C119,C312 | 100nF ±10% 16V Ceramic Capacitor X5R 0201 | 200 | 100 | 0.0029 | 0.58 | https://www.lcsc.com/product-detail/C307380.html
49 | C19702 | CL10A106KP8NNNC | Samsung Electro-Mechanics | 603 | C104,C110,C114,C116,C266,C270,C275,C283,C286,C294,C309,C321 | 10uF ±10% 10V Ceramic Capacitor X5R 0603 | 20 | 20 | 0.0822 | 1.64 | https://www.lcsc.com/product-detail/C19702.html
50 | C62164 | 0201CG180J500NT | FH | 201 | C120,C121,C317,C318 | 18pF ±5% 50V Ceramic Capacitor C0G 0201 | 100 | 100 | 0.0029 | 0.29 | https://www.lcsc.com/product-detail/C62164.html
51 | C161488 | GRM033R71E222KA12D | muRata | 201 | C262,C264,C272,C280,C303 | 2.2nF ±10% 25V Ceramic Capacitor X7R 0201 | 100 | 100 | 0.0052 | 0.52 | https://www.lcsc.com/product-detail/C161488.html
52 | C86295 | CL10A226MP8NUNE | Samsung Electro-Mechanics | 603 | C263,C268,C278,C297 | 22uF ±20% 10V Ceramic Capacitor X5R 0603 | 10 | 10 | 0.038 | 0.38 | https://www.lcsc.com/product-detail/C86295.html
53 | C122469 | XFL4020-222MEC | Coilcraft | SMD,4x4mm | L7,L8,L9,L10,L12 | 8A 2.2uH ±20% 21.35mΩ 3.7A SMD,4x4mm Fixed Inductors RoHS | 5 | 1 | 1.3566 | 6.78 | https://www.lcsc.com/product-detail/C122469.html
54 | C602037 | CL21A226MAYNNNE | Samsung Electro-Mechanics | 805 | C311 | 22uF ±20% 25V Ceramic Capacitor X5R 0805 | 10 | 10 | 0.1135 | 1.14 | https://www.lcsc.com/product-detail/C602037.html
55 | C17291088 | GCM033R71A122KA03D | muRata | 201 | C315 | 1.2nF X7R ±10% 10V 0201 Ceramic Capacitors RoHS | 100 | 100 | 0.0094 | 0.94 | https://www.lcsc.com/product-detail/C17291088.html
56 | C88914 | GRM0335C1H680JA01D | muRata | 201 | C316 | 68pF ±5% 50V Ceramic Capacitor C0G 0201 | 100 | 100 | 0.0017 | 0.17 | https://www.lcsc.com/product-detail/C88914.html
57 | C505464 | CC0201KRX7R9BB102 | YAGEO | 201 | C319 | 1nF ±10% 50V Ceramic Capacitor X7R 0201 | 100 | 100 | 0.0018 | 0.18 | https://www.lcsc.com/product-detail/C505464.html
58 | C133346 | ESD8472MUT5G | onsemi | X3-DFN-2(0.3x0.6) | D5,D12 | 15VC 20VC Clamp 3A@8/20us Ipp ESD DIODE X3-DFN-2(0.3x0.6) | 5 | 5 | 0.0826 | 0.41 | https://www.lcsc.com/product-detail/C133346.html
59 | C598848 | MT25QU128ABA8ESF-0SIT | micron | SOIC-16-300mil | IC1 | SOIC-16-300mil Microcontrollers RoHS | 1 | 1 | 10.2374 | 10.24 | https://www.lcsc.com/product-detail/C598848.html
60 | C613841 | 93C46B/P | MICROCHIP | PDIP-8 | IC3 | 1Kbit 4.5V~5.5V 2MHz SPI PDIP-8 Memory (ICs) RoHS | 1 | 1 | 1.0827 | 1.08 | https://www.lcsc.com/product-detail/C613841.html
61 | C3747719 | ADP1754ACPZ-1.3-R7 | ADI | LFCSP-16(4x4) | IC10,IC11 | 1.3V Positive Fixed LFCSP-16(4x4) Voltage Regulators - Linear, Low Drop Out (LDO) Regulators RoHS | 2 | 1 | 4.6333 | 9.27 | https://www.lcsc.com/product-detail/C3747719.html
62 | C892685 | NCP700BSN33T1G | onsemi | TSOP-5-1.5mm | IC13 | 3.3V Positive Fixed TSOP-5-1.5mm Voltage Regulators - Linear, Low Drop Out (LDO) Regulators RoHS | 1 | 1 | 1.2691 | 1.27 | https://www.lcsc.com/product-detail/C892685.html
63 | C658468 | ADM7160AUJZ-1.8-R7 | ADI | TSOT-5 | IC14 | Linear Voltage Regulator IC Positive Fixed 1 Output 200mA TSOT-5 | 1 | 1 | 2.7671 | 2.77 | https://www.lcsc.com/product-detail/C658468.html
64 | C5410688 | 69145-210LF | Amphenol | - | J1 | Open-Top 2.54mm Shunts, Jumpers RoHS | 1 | 1 | 1.0308 | 1.03 | https://www.lcsc.com/product-detail/C5410688.html
65 | C3168185 | FH19SC-22S-0.5SH(09) | HRS | SMD,P=0.5mm,Surface Mount,Right Angle | J6 | FFC/FPC Connector 22 Position 0.5mm Pitch Bottom Contact Surface Mount, Right Angle -55℃~+85℃ | 1 | 1 | 1.7125 | 1.71 | https://www.lcsc.com/product-detail/C3168185.html

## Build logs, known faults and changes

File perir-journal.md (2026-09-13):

# PeriR — Journal Export

- Exported at: 2026-08-25T12:12:30Z
- Project ID: 317
- Entries: 12

## Entry 1
- ID: 121
- Author: alfder
- Created At: 2026-03-17T08:27:40Z

### Content

Now this is a really hard project and tons of time will go into the design and firmware process. Along with that I need to learn the various complex signal processing concepts and HDL code that goes into this project. But nowadays theres more and more references and support on the internet. I am hoping to learn a looot from this project. Wish me luck!

So what am I doing?
I am making a carrier board that has an SDR on it with the Compute Module 4 acting as the Computer. SDRs need a computer for running apps such as GNU Radio or SDR++. 

Now what is an SDR?
A software defined radio is a device that moves signal processing from traditionally implemented analog circuits to software after the radio signal has been converted into digital samples.

An SDR can do :

- FM radio receiver
- ADS-B aircraft tracking
- satellite communication
- GSM or LTE research
- GPS receivers
- spectrum analyzers

SDR can be a transmitter, receiver, or transceiver. I'm hoping to make a transceiver. 

A Transceiver SDR is an SDR with both a transmitter and a reciever hence the name Transceiver. 

A Transceiver SDR has the following paths:
Receive path:
Antenna → RF front end → ADC → FPGA/CPU DSP → Software

Transmit path:
Software → DSP → DAC → RF upconverter → Power amplifier → Antenna

Now I need to do research on implementing these paths. Now, it is made easy cus theres lots of SDRs on the internet and some of them provide schematics.

So while looking for reference designs and guides I stumbled up on FreeSRP an Open Source SDR project by Lukas Lao Beyer. His work is incredible and I will be using his project as the primary reference for this project. (Link to hsi website: http://electronics.kitchen/misc/freesrp/ ) 

So after some research I have understood that for building my SDR there are some major groups of components

I'm starting off with hunting for the major components for each group according to:

- affordability
- availability
- routing 
- complexity 
- community and support.


TRANSCEIVER:
The Transceiver converts radio-frequency signals to and from digital I/Q samples by performing RF tuning, mixing, filtering, and ADC/DAC conversion between the antenna side and the digital processing system.

I've decided on the AD9364 as it is widely used and documented and has a fairly large Frequency Band  (70 MHz to 6.0 GHz) and Bandwidth (200 kHz to 56 MHz).

FPGA:
The FPGA is what does the Digital Signal Processing in order to make the data usable for software and the interface b/w the Transceiver and the CM4.

So what i need for the FPGA is a chip with a decent amount of LUTs (Look Up tables).  45k+ LUTs is enough for an SDR.

I've got some options like the  
- XC7A50T-2FTG256C (50K LUTs)
- XC7A100T-2FTG256C (100K LUTs)
- ECP5 LFE5U-45F (45K LUTs)

I've decided on XC7A50T-2FTG256C for my FPGA as is cheaper and has good documentation on the internet with this use case as opposed to the Lattice ECP5 and also I have some experience with Vivado.
 
POWER: There is quite a few power rails they
include 5V , 3.3V ,1.8V ,1.3V, 1.0V .
This is the IC list:

- 5V USB-C input
- 1.0V TPS62130
- 1.8V TPS62130 
- 3.3V TPS563201
- 1.3V TLV743P
Power Tree: 

Interfaces:
Onbaord the CM4, There are two major data transfer protocols the USB-2 and PCIe Gen-2 . USB-2 is very slow for throughput of the SDR (AD9363 at 61.44 MSPS, 2x 16-bit = ~245 MB/s)

Since the CM4 has a PCIe Gen - 2 with a throughput of around 350MB/s which is more than enough for the the throughput of the SDR. 

So this is my mind map of this project.

### Recording Links

- https://www.youtube.com/watch?v=TJHox4jQnp0

## Entry 2
- ID: 139
- Author: alfder
- Created At: 2026-03-17T19:52:55Z

### Content

There is a major change to the choice of  the FPGA to be used. Instead of using the XC7A50T-2FTG256C I will be using either the XC7A50T-2CSG325C or XC7A35T-2CSG325C( both same share the same pinouts but require different amouts and values of decoupling capacitors). I will explain this change in the PCIe section.
 

---
FPGA Power & Power Decoupling:
---
- ***FPGA Power***:
Now there are different voltage inputs into the fpga for different parts of the FPGA. Now the DS181 provides a good explaination on what these different pins do and the reequired voltages.So ill try to give a brief explaination of each power input. 


    - ***VCCO***:
VCCO is voltage that powers the I/O buffers in the FPGA and sets the signaling standard of the "bank". For example in the XC7A35T-2CSG325C, there is no High Performance bank that is required for LVDS that is used as a standard for the communication between the transceiver. So we can introduce the LVDS standard by supplying a bank VCCO with in this case 2.5V instead of 1.8V that is used for the CMOS standard. Ill explain what are the different standards later. (In the transceiver jorunal entry)
In the XC7A35T-2CSG325C there are 4 banks and their inputs are VCCO_0(config), VCCO_14, VCCO_15,VCCO_34 (I chose bank 34 for LVDS).
    - ***VCCBRAM***:
VCCBRAM provides 1V for powering the on chip Block RAM. 
    - ***VCCADC***:
It is the voltage(1.8V) used to power up the analog to digital converter. It powers the analog circuits in chip that measure temp voltage (XADC) and external analog inputs.
    - ***VCCINT***:
It provides 1V to the LUTs, Flip Flops etc. 
    - ***VCCAUX***:
It provides 1.8V to the Clock management blocks (PLL/MMCM), JTAG. 
    - ***MGTVCC & MGTVTT***:
MGTVCC provides 1V to gigabit transceiver analog cirucits present on the chip. MGTVTT provides the termination ref voltage to the CML termination network inside the chip so the high speed signals transmitted wont relfect back.

- ***Decoupling:***
Now this varies from FPGA to FPGA as their pin layouts and no. of LUTs change. AMD has provided a handy datasheet (UG483) in which they tell us recommended PCB design practices and Infomation on the amount of Decoupling Capacitors for each power input. For the XC7A35T-2CSG325C the capacitors and their amounts is shown the below table from the datasheet.




this is the schematics for decoupling. 

---
FPGA CONFIG & SPI FLASH
---
FPGA configuration was pretty straightforward. Datasheet UG470 provided info on wiring almost every pin and the wiring for the pins like DXP/N was solved using datasheets and forums.



***Config Mode***: 
We select the configuration mode using MODE pins. They form a 3-bit bus. The following table shows different combinations that are used to select the mode:


- ***Master SPI***:
Master SPI mode allows the FPGA to read the bitstream generated using HDL to do various tasks from the SPI Flash. 

***SPI Flash***:
MT25QU128ABA8ESF-0SIT is the flash that used here. It has 16MB(128Mb) of Flash. The connections are pretty standard even if you use a different manufacturer.
SPI Flash stores the Bitstream file produced in Vivado (xilinx) so you dont have to flash the same bitstream every time you boot.

Connections were done with reference to the flash's datasheet and FreeSRP's and other reference designs.



---
FPGA Clock
---
A clock is essential for the sequential logic inside the FPGA like Flip Flops. Flip Flops change their state every rising edge or beginning of a wave crest.  

PLLs(Phase-Locked Loop) also need a reference clock to make new stable clocks by locking one clock signal to another. PLLs help to dissipate jitters for high speed signals.  

Oscillator ive gone ahead with is the EPSON SG-8018CA 100.0000M-TJHSA0.  There is no special reason for the selection any 100MHz 1.8V oscillator will do.



---
PCIe
---
For PCIe implementation I went thru some reference designs and found a group of pins in anew bank called MGTAxxx pins. I couldn't find them in the FTG256 fpga because it seems they didn't bond that part to the I/O. I spent hours on find the reason. And it was right in front of my eyes btw. In the main 7 series FPGAs datasheet they mentioned something about GTP transceivers. Turns out these MGTAxxx pins were the I/O for them and they are 
used to transmit high speed signals like PCIe etc. 
So, I quickly found a suitable fpga with the pinout that includes GTP  which is the CSG325 with 4 GTP transceivers.

CM4 which has PCIe Gen2 with one lane. I have followed the UG482 datasheet and reference designs on the internet for the wiring. 

Speed is around 4Gbps (400MB/s) after after 8b/10b encoding.  
There is a Reference Clock incoming from the CM4 for the PLL inside GTP block.

The RX, TX and the REFCLK are diffrential pairs with an diffrential impedance of 85ohms for the TX AND RX and 100ohms for REFCLK.

 Oop i found some connections I missed.
nRST and nREQ. These were some important pins too. nRST intializes the PCIe and nREQ tells the CM4 to output the refclk. 



---
FPGA I/O
---
This is the place the fpga interfaces with other ICs and signals. VCCO_14,VCCO_15,VCCO_34 all power the banks here. 

***Bank 14 and Bank 15***:
Bank 14 and Bank 15 use the LVCMOS18 standard. Hence they handle the single ended signals. They act as an interface b/w the Gigabit Ethernet,  Some PCIe Signals, SPI flash etc. Later on i will be using some of them to drive Status LEDs and remaining ones will be probably used as GPIO. 

Your supposed to drive the Clocking I/O to pins with the name MRCC or SRCC they are special pins.

***Bank 34***:

This bank is powered with 2.5V and uses the LVDS_25 signalling standard. It has a different signalling standard because LVDS allows for double ended signals therefore maximizing the the throughput from the AD9364. This bank is connected to AD9364 LVDS differential pair signals and its SPI and other pins. 
I went thru tons and tons of datasheets and forums and reference designs(I couldn't find any that uses LVDS for ad9364). The datasheets and people on reddit mentioned LVDS implementation on this fpga required 2.5V to its VCCO banks(This is because my selection only has High Range banks out therefore the i/o buffers need a higher voltage to produce the LVDS signals).  But the thing is I asked claude to help me find references but it started talking about termination resistors and all that. I'm still not sure about the LVDS part but I did find a person with almost the same components and questions on LVDS implementation as me. The person who answered was a analog circuits employee so I think my doubts on the transceiver side are kinda cleared but my FPGA side still is doubtful.  


FPGA I/O

---

**Role of AI in this project:**
Not using AI in this day and age is just straight up inefficient. It helps you retrieve info very fast, helps you organize, basically just speed up R&D. It helped me with finding respective datasheets, reference designs and clearing my doubts on some concepts. I also used AI to help me keep check of essential parts of the design process by uploading different reference schematics for it's reference. Never trust AI to help you with connections or design and always ask for references to the information they output.
___

---

### Recording Links

- https://www.youtube.com/watch?v=OnGQM5hx2SY
- https://www.youtube.com/watch?v=5Uldx5--G7g
- https://www.youtube.com/watch?v=YmUaideF6rw
- https://www.youtube.com/watch?v=ljv5lHSSsYQ
- https://www.youtube.com/watch?v=UXiI6siYtjU
- https://www.youtube.com/watch?v=Kb2GCJdru1c
- https://www.youtube.com/watch?v=kMbWr43iKdQ

## Entry 3
- ID: 519
- Author: alfder
- Created At: 2026-03-27T04:30:58Z

### Content

---
TRANSCIEVER
---
Its been a slow week. I've procrastinated a lot and my school started this week. On top of that reference materials and datasheet like the ones provided by AMD for the FPGA were REAL scarce for the AD9364. The ones they provided were more vague and had a real steep learning curve. So I had to resort to help from AI for understanding what's going on and help with choosing parts. But as I've said before AI should be used cautiously especially here because there's less information to work on. 
I've mainly stuck to two reference designs the FMCOMMS4 and FreeSRP both using the AD9364. The FMCOMMS4 from Analog Devices(AD9364 OEM) uses the LVDS signalling standard so this design was my primary.

---
POWER AND POWER DECOUPLING:
---
I used the AD9364 reference manual pg. 111, FreeSRP and FMCOMMS4 for wiring and choosing the values and quantity of decoupling caps. The Power side was pretty straightforward with almost all the pinouts described in the datasheets but the amount and quantity of power decoupling was more vague so I used the FMCOMMS4 and mainly the FreeSRP for reference. 


---
INTERFACE TO FPGA:
---
So this part had me running around in circles. I had to choose a signalling standard to interface with the FPGA. Now what is a signalling standard? Signalling standards in electronics define voltage levels, current loops, or differential pairs used to transmit data, control systems, and ensure compatibility between components. Now in the AD9364 you have two options CMOS(Complementary Metal Oxide Semiconductor?) and LVDS(Low Voltage Differential Signalling). The difference between them is that LVDS uses the differential mode of transmission and CMOS uses the single ended mode. Using differential signals offer wayyy lower EMI production as the pair of wires (N and P) cancel each other out. LVDS also offers faster data transfer as there's double the amount of wires for transmission. But it comes at cost of harder routing as you have to take care of impedance and the pair should have the same length. 


As you can see you get max use of the ad9364 by using LVDS. Hence I went for it. Hopefully it wont come back and bite me while routing. 

Now the Artix-7 FPGAs need 2.5V as a VCCO input to a whole bank to implement LVDS. Due to incorrect info from AI I spent quite a bit of time on figuring this part. This why you never trust AI. It said 1.8V LVDS is possible but really it was only possible for other models. Finally after come help from a forum. I had confirmed this part of the transceiver. 


---
MISCELLANEOUS 
---
This part also was done mostly thru reference designs mostly the FMCOMMS4 and the 2 datasheets. 
Clock used here is 40MHz with a load capacitance of 10pF. Now the datasheet specifies a range b/w  19MHz and 50MHz but they've already tested with the 40MHz clock so, I've gone ahead with it. 
I still have confirm that the CTRL I/O can be used with a 1.8V bank because I've run out of pins on the BANK 34. Rn its js a global bus. 
According the forum mentioned before SPI pins and other interface pins should also be connected to the 2.5V Bank. 


---
TX AND RX
---
This is the infamous Black Magic section of the board. I am still yet to fully understand what's going on. Theres a lot of complex concepts and maths involved in the mechanics of this part. But I've been going thru some materials to understand whats going on and how to implement it. Since its my first time designing anything with RF (Ik its a stupid thing to do) I've decided to be "heavily inspired" by the FMCOMMS4 design and implement an identical design on my board except the 2.4GHz RX AND TX to keep complexity and costs low. Hence I'm using a wideband balun (RF Transformer) the TCM1-63AX+. It has a very low insertion loss throughout the band and
is readily available and relatively cheaper. 

Now what is a balun? As the schematic shows the AD9364 RX AND TX ports are differential(balanced) so the balun (BALanced and UNbalanced) basically convert the differential signals to unbalanced signals toward or from the antenna. But what is Insertion Loss. Insertion loss is the reduction in signal power caused by inserting a component, here a balun into a transmission line. It is measured in decibels (dB). At its peak the TCM1-63AX+ has a insertion loss of 1.8dB @ 6GHz which is really good for a wideband RF Transformer. 


_____________________________________________________________
This design is not final and I may make changes to it if I find something stupid I did. Also ill submit my design on the ANALOG DEVICES ENGINEER ZONE FORUM to get another set of eyes on it. 

I'm dreading the day I have to route this 😭🙏.

### Recording Links

- https://www.youtube.com/watch?v=NvBK0wFQPmI
- https://www.youtube.com/watch?v=Hv3sPzH87ws
- https://www.youtube.com/watch?v=9K3Qde5C_ho
- https://www.youtube.com/watch?v=zVtxisBByR8
- https://www.youtube.com/watch?v=yYPSr4PqSw8
- https://www.youtube.com/watch?v=Om-Wifa1wxA
- https://www.youtube.com/watch?v=vnmhE4KmVkg

## Entry 4
- ID: 973
- Author: alfder
- Created At: 2026-04-02T21:37:20Z

### Content

So I have specified before that I will use a 1G Ethernet port for standalone interface. But the thing is its way harder than USB to implement in the FPGA. This session was basically tons of research into USB2 vs Ethernet vs USB3.  

I wasn't pretty sure about using USB3 or ethernet or USB2. I just needed something that is simple and easy to route. Initially I wanted the board to be capable of standalone operation but since USB3 AND ETHERNET has more wiring and routing which just increases more possibilities of errors. I decided to keep this interface just to test the connection between the AD9364 and the FPGA before heading deep into writing firmware for the PCIe interface.


USB 2 Ref Schematics.
---

USB3 ref schematics
---

### Recording Links

- https://www.youtube.com/watch?v=dZanAVErYew
- https://www.youtube.com/watch?v=IHejjJGaHLU

## Entry 5
- ID: 1005
- Author: alfder
- Created At: 2026-04-03T08:30:38Z

### Content

So in these sessions I left the Direct FPGA interface for a bit. I decided to move onto the CM4 interface to the FPGA and peripherals. 

It was soo hard to find a good kicad CM4 symbol. I spent quite some time looking for it.  

CM4 datasheet provided by RPI was enough for drawing the schematics. I also used the Pincushion board and MirkoPC as my reference drawings. Everything was smooth sailing till I reached the USB interface for the CM4. I didn't want the CM4 to act as a slave. I didn't need a switch. I didn't want to draw and route a USB hub So I decided to only have one USB-A port. When I need to add peripherals like a keyboard and a mouse ill just use a hub or something. 


### Recording Links

- https://www.youtube.com/watch?v=ONy4QQIOlIA
- https://www.youtube.com/watch?v=YVME6g7f7fs

## Entry 6
- ID: 1007
- Author: alfder
- Created At: 2026-04-03T08:36:07Z

### Content

Okay so for the Direct FPGA interface after a lot of back and forth I have decided to go ahead with USB2 with the FT2232HL. For USB 3 I knew I wasn’t gonna use the FX3 since it was too complex. I found another easier USB3 controller (WCH CH347) but it was Chinese and without any good datasheets and reference designs it would be a gamble using it. Ethernet was too hard for me to implement so I gave up on sticking to it. USB 2 seemed the best option at the cost of incomplete utilization of the speed that the transceiver offers. It really didn’t matter anyway because it was connected to a computer via PCIe.  

The FT2232HL offers 480Mb/s when it is in SYNC fifo mode. So I quickly found the datasheets. There were two of them. The main datasheet had the power and EEPROM wirings and the second datasheet provided a pinout map for a SYNC FIFO. 

Clocking crystals are notoriously hard to find. Its not that they are scarce but its hard to find ones in stock in LCSC.

 

----

Now the FT2232HL uses 3.3V for signalling and the available banks were both 1.8V so I decided to change bank 15 to 3.3V LVCMOS. That’s when it struck me that even the CM4 PCIe RST and REQ might use 3.3 v signalling. So I doubled checked with the datasheet. I had nothing so I checked the PinCushion schematics and sure was I correct. So changed the BANK VCCO to 3.3V. Crisis averted. 

 

---

I also started adding notes to the places I still have doubts about. 




---

I did not know we could submit journaling time 💔 Imma start recording journaling from now on.

### Recording Links

- https://www.youtube.com/watch?v=m53aE6QPPwM
- https://www.youtube.com/watch?v=B3OFvt6Nt-0
- https://www.youtube.com/watch?v=LDokv9RmtOM
- https://www.youtube.com/watch?v=06v2nr9xiR0
- https://www.youtube.com/watch?v=KyGLp88eso8

## Entry 7
- ID: 2601
- Author: alfder
- Created At: 2026-04-17T19:12:47Z

### Content

Ok so this week has some massive changes to the project. Initially I wanted to create an SDR that is much like the HackRF Portapack but more powerful and can run Linux. That was my intended goal. So when I started researching into this project back in January, I initially wanted to use the Zynq7020. This chip is a combination of an ARM Cortex A9 and an Artix-7 FPGA with 85K LUTs. Now after weeks of research I decided to move away from this chip because I couldn't find any sources or projects or Linux distros that could run a GUI. That meant I had to make my own Linux distro. I wasn't too confident in doing this. I didn’t even know Linux properly, how was I gonna create a whole new distro? So I decided to split the work into a CM4 and an Artix-7.
Now here's the twist. While I was researching into the firmware development of the HAT, I stumbled upon Kuiper Linux by Analog Devices. It's based off Raspberry Pi OS and has kinda native support for its product. "Kinda" because it's actually support for the dev boards, but I could work with that. Otherwise I had to make my own drivers and write custom Verilog for the HAT board. On top of that it has its own HDL and has support for Zynq7020 (Zedboard). So since I wasn't that confident in my programming skills I decided to basically redesign the FPGA part of the board.
FPGA:
So quickly I placed all the components and started with the design. Since I already had worked on the Artix-7, I didn’t need to research every pin again. I knew what they were and what I should do. I copy-pasted the decoupling and the config and just added or changed the values of the components according to the UG585 and UG933.
•	Clock: Now I need two separate clocks, one for the PS (Processing System) (33.33 MHz) and PL (Programmable Logic) (100 MHz). Wiring is standard crystal wiring and connected to the FPGA using UG585. 
•	QSPI flash: I don’t think it’s needed since I’m booting from the SD card anyway, but I added it just in case. This time all the data lines are in use. It is wired according to UG585. 
•	Configuration: There are some changes. The CFGBVS pin is pulled up to 3.3V now since the VCCO_0 bank is now 3.3V. Due to this change the VREF on the JTAG header and VCCO_0 decoupling should also be changed to 3.3V. RSVDVCC should be tied to VCCO_0 according to UG585. 
•	Boot Config: I followed the UG585, Zedboard and ADRV9364 schematics for this. Its simple, just choosing boot device. I just got confused because the FLASH and the Switches share some pins but it doesn't matter cus they only gonna be used initially.
•	I/O banks: 35 and 34 use 2.5V LVDS and banks 33 and 13 use 3.3V (I might change one of them to 1.8V because I plan on making an accessory for the board). The AD9364 I/O is wired according to the FMCOMMS4 and Zedboard connections so setup will be easier.

 
•	RAM: I’m using 128MB ×2 DDR3 chips for RAM. Same configuration as the Zedboard (might upgrade to 1GB). Wiring is straightforward. Signal lines need 40 ohm termination.



### Recording Links

- https://www.youtube.com/watch?v=IkE0x3leGws
- https://www.youtube.com/watch?v=nfOYPGpUw8M
- https://www.youtube.com/watch?v=_9JnU3TCBzA
- https://www.youtube.com/watch?v=8SminApInEQ
- https://www.youtube.com/watch?v=GTfsHB5MKPQ
- https://www.youtube.com/watch?v=lzsiiVnWBGs

## Entry 8
- ID: 3105
- Author: alfder
- Created At: 2026-04-20T20:44:08Z

### Content

Interfaces:
Display:
For display I decided to follow the zedboard’s HDMI design because its natively supported by Kuiper Linux so ill have an easy time seting up the display. ADV7511 is an HDMI transmitter from Analog Devices.
Now the thing is I eventually wanted to make my board handheld like the Portapack but I’d need a HDMI to DSI or RGB convertor for it to work on a panel screen. I initially decided to follow the ADAFRUIT’s TFP401 design for this but then i changed my mind and decided to make a separate HAT board with the TFP and maybe a keyboard after the main board and  firmware is over. The design was getting to large and I was scared that I’d mess up something cus its so big. 
USB-OTG:
USB On The Go interfaces the PS with peripherals like a keyboard or mouse. I’m to lazy to wire a hub on the board so I’ll probably get an off the shelf hub. The design was done according to the Zedboard, ADRV9364-Z7020 and the UG585 datasheet.
Ethernet:
So its back again. I needed the ethernet as a back up for the display and OTG. Ill probably use this for setup and testing. The design was done according to the Zedboard and the UG585 datasheet.
SD card: 
SD card is the primary storage and boot up option for the board. It stores the boot up files, FPGA bitstream files and Kuiper linux. So it is really important I get this part correct. Since the SD card works on 3.3v LOGIC AND THE MIO1 bank works on the 1.8V logic (cus majority of the other interfaces work on 1.8v) we need the level shifter. The design was done according to the Zedboard and the UG585 datasheet.

Power: 
This is also a really crucial part of the board.  
There are mainly 8 power rails on the board.
1.8V  
3.3V  3,3VTX
2.5V
1.0V
1.3V,1V3TX
1.5V
0.75V
5V

0.75V, 1.0V, 1.5V, 1.8V, 2.5v, 3.3V:
These rails are mainly used by the Zynq and interfaces.
According to the DS187 DATASHEET( PS Power‐On/Off Power Supply Sequencing PG.8) requires that the powering sequence be  VCCPINT(1.0V), then VCCPAUX and VCCPLL (1.8V )together, then the PS VCCO supplies (VCCO_MIO0, VCCO_MIO1, and VCCO_DDR)(3.3V,1.5V, 0.75V).
(PL follows the same scheme)

This is sequencing is done by making use of the EN(ENABLE) and PG(POWER GOOD) pins on the POWER ICs

Choosing the Power ICs:
I’ve chosen the Power ICs according to Availability, Cost, Routing Difficulty, Support, Current and Power Switching Frequency (EMI reduction)(1.25MHz).
1.0V, 1.8V:
I needed a buck that can provide up to 3A of current as these pins take most of the heavy load by the board. In FreeSRP’s design he uses TPS62130A to provide the required current. You set the voltage with a Resistor divider circuit at FB pin. The selection of the resistor value is done by this equation. 


Inductor selection was done with reference to the FreeSRP and the  TPS62130A datasheet. 



3.3V, 2.5V, 1.5V:
I wanted to deal with the least amount of wiring so I was looking for a buck with 3 outputs. I eventually found the TPS65251-3RHAR. It provides 3A-2A-2A current output. Since the 3.3 rail is used more I decieded to give it the 3A output. The voltage is selected using the FB resistor divider circuit using the same equation as before. 
Inductor was chosen using the following equations.
 

0.75V
This voltage is the termination voltage for the DDR. It is supplied by the MAX1510ETB+. 
1.3V,1.3V_TX
It is the primary voltage rail of the AD9364. I have used the ADP1754ACPZ-1.3-R7 as it is recommended by Analog Devices for its stability. 
5V:
It is supplied by external power source thru a power connector(TBD)
GPIO:
I am using the DF40C-100DS-0.4V_51 found on the CM4 as my gpio header as it has a small form factor.  I want to eventually make a HAT with a screen and other peripherals.
I am also routing the HDMI and OTG signals to it. 
Miscellaneous:
PS_POR_B:  A crucial reset pin for stable operation as it waits for all power system to be up and running before starting the PS.  
PS_SRST_B: Reset button
PS_VREF: 0.9V rail refer below 


Boot up headers to buttons
QSPI Flash from 3.3V to 1.8V 
Power Amp for TX:
PGA-102 is a power amp that works on 3.3v hence a separate power ic for it for clean power. TX output from the AD9364 is kinda weak.  

### Recording Links

- https://www.youtube.com/watch?v=ZoyeQua38GY
- https://www.youtube.com/watch?v=LApXd7OLbGI
- https://www.youtube.com/watch?v=Jo44Lv3l1FI
- https://www.youtube.com/watch?v=aQgmeYO2SZY
- https://www.youtube.com/watch?v=x6juVCaHEsU
- https://www.youtube.com/watch?v=xqSQYhX0v9s
- https://www.youtube.com/watch?v=4CxgTthxZf8
- https://www.youtube.com/watch?v=HKIHF6WvBSk
- https://www.youtube.com/watch?v=mK2b_OkVO_A
- https://www.youtube.com/watch?v=o3R0KbsihcE
- https://www.youtube.com/watch?v=Bdep1bviY-k
- https://www.youtube.com/watch?v=o3By00YozLs
- https://www.youtube.com/watch?v=O8eKWQ806ms
- https://www.youtube.com/watch?v=X0KCtDnTdiU

## Entry 9
- ID: 4064
- Author: alfder
- Created At: 2026-04-26T15:49:47Z

### Content

Im finally done with component selection, drawing the schematics and assigning the footprints. 
GPIO:
I decided to place two DF40C-100DS-0.4V_51 cus it would make the connection with the hat more stable. 
MISCELLANEOUS;
I made some changes and essential missing connections (PUDC_B and SD card DETECT AND WP)
I added the AD7291BCPZ also in the FMCOMMS4 and ADRV9364. It provides power statistics of the whole board.

Verification:
Verification is an important thing to do especially when the board is this complex and big.  
I found some massive errors and missing connections:
•	PS boot up config: Idk what happened the variable pins were connected wrong. I fixed them according to UG585 again.
•	Some resistor values in power section (COMP pins for the TPS65251-3RHAR)
•	CEC clock for HDMI was missing and ESD protection for CEC. 
•	3V3 net were mislabeled as 3.3V in some places
•	ESD protection was missing for USB-OTG
•	Some OTG were left unconnected. 
I hope to do another Verification next week. 
Assigning Footprints
Assignment of the footprint were done according to the UG933 datasheet and BOMs of PlutoSDR, FMCOMMS4, Zedboard, FreeSRP.  

### Recording Links

- https://www.youtube.com/watch?v=bY7aJ7XnGC0
- https://www.youtube.com/watch?v=_Kiju906hfU
- https://www.youtube.com/watch?v=bm7DiiWbsPk
- https://www.youtube.com/watch?v=Ccw_OYd3NGk
- https://www.youtube.com/watch?v=g1MPIJSFosk
- https://www.youtube.com/watch?v=nf1j7d8-XA4

## Entry 10
- ID: 10349
- Author: alfder
- Created At: 2026-05-30T08:43:30Z

### Content

So after a long break due to exams and a holiday im finally back.
After verification I started with general placement, power planes and via placement
I also entered the impedance values for the traces on each signal layer and delay units. 
I’ve decided to make it a 8 layer board atleast due to the density of signal and power traces present.
Via placement is important for routing and component placement. I followed the dog-bone method instead of the via in pad because of the space it gives for routing and placement. 



### Recording Links

- https://www.youtube.com/watch?v=10gsAFUqDF4
- https://www.youtube.com/watch?v=UkJlRLl4Tro
- https://www.youtube.com/watch?v=Uvpqn_mjOvE
- https://www.youtube.com/watch?v=7jGfMwrIXD8
- https://www.youtube.com/watch?v=OwRprZUsEHw
- https://www.youtube.com/watch?v=5xcBoU6tMyc
- https://www.youtube.com/watch?v=UB98xOdd0dk
- https://www.youtube.com/watch?v=fQEguXu7LuQ
- https://www.youtube.com/watch?v=rWCEdCNkBhk
- https://www.youtube.com/watch?v=pk2SxVGYq2k
- https://www.youtube.com/watch?v=KeT1FOpSYd0
- https://www.youtube.com/watch?v=J1YXMxbBGEc
- https://www.youtube.com/watch?v=QMl1tkEnfWI

## Entry 11
- ID: 10354
- Author: alfder
- Created At: 2026-05-30T10:03:56Z

### Content

I forgot to submit these videos. 
They show the final general component placement.
Wish me luck for routing this!


### Recording Links

- https://www.youtube.com/watch?v=-bWUE7-RFLM
- https://www.youtube.com/watch?v=URoZFXsCmVg
- https://www.youtube.com/watch?v=IuD2v4Mgs3g

## Entry 12
- ID: 16079
- Author: alfder
- Created At: 2026-06-23T12:15:34Z

### Content

So, I’ve decided to make PeriR an MVP and returned to my original plan on making CM4 SDR HAT. This is because I wanted to qualify for the event and DDR routing seems out my level, especially routing two of em. 
So, I got started right away with power schematics cus it was the only thing I didn’t complete on the HAT before Zynq. I used the TPS62130A separately for each rail instead of the 3 in 1 buck cus it would make drawing planes easier and less constraint. 
Then I got started with the general placement of the major components, then the bypass and decoupling and then resistors. It went fast cus I practiced with the previous design. 
Power Planes were also a breeze cus of the practice.
I was intimidated by the ratsnest in the first design. Bro, what was that!? This one was tamer but still complex. 
I started routing the TPS62130A chips. I just followed the example given in the datasheet and my wiring diagram.
Next, was the USB 2.0 interface the FT2232HL.
After that I started with the connections b/w the AD9364 and FPGA. Here I made a small mistake by not doing the dogbones first but according to my research it’ll be alright. 
(Before I submit to a fab, I’ll probably reroute it again.)
 FPGA and AD9364 Power delivery was done through Power Planes and Thicker Traces wherever possible. 
CM4 and its interface’s routing was done according to the CM4 datasheet. PCIe needs proper impedance control and length matching but it’s laxer cus it’s only PCIe 2.0. 
RF routing was done according to examples from the FreeSRP and FMCOMMS4. It is a coplanar arc with no solder mask on top. All the layers below the RF section are ground planes. 
I decided to keep the ref values for only the main components and some logos on the silkscreen.



### Recording Links

- https://www.youtube.com/watch?v=QOjy-xeKWOM
- https://www.youtube.com/watch?v=KX0_TyagnQ4
- https://www.youtube.com/watch?v=sq312k_K0cA
- https://www.youtube.com/watch?v=9CMUil3-TLw
- https://www.youtube.com/watch?v=E2RAGUNgbH8
- https://www.youtube.com/watch?v=AwUKXpqDrTw
- https://www.youtube.com/watch?v=tMLclXklSSs
- https://www.youtube.com/watch?v=K7RCws3XndE
- https://www.youtube.com/watch?v=KVBkVN54vN8
- https://www.youtube.com/watch?v=ln8Zk-9Xfxo
- https://www.youtube.com/watch?v=xQvRE2JUEbM
- https://www.youtube.com/watch?v=y9_g-WkQgWU
- https://www.youtube.com/watch?v=_hF0sZb-mIM
- https://www.youtube.com/watch?v=WS8lGpnOEnA
- https://www.youtube.com/watch?v=04tepWEY1TU
- https://www.youtube.com/watch?v=vx6_bkyNiBs
- https://www.youtube.com/watch?v=BC715uGVJ1g
- https://www.youtube.com/watch?v=Z-N89I6z3xo
- https://www.youtube.com/watch?v=fudO6M7lvkU
- https://www.youtube.com/watch?v=qBprEguQdMI
- https://www.youtube.com/watch?v=sriJZpKvgRI
- https://www.youtube.com/watch?v=pKTFVFPYRbY
- https://www.youtube.com/watch?v=ryHLZIhWXMQ

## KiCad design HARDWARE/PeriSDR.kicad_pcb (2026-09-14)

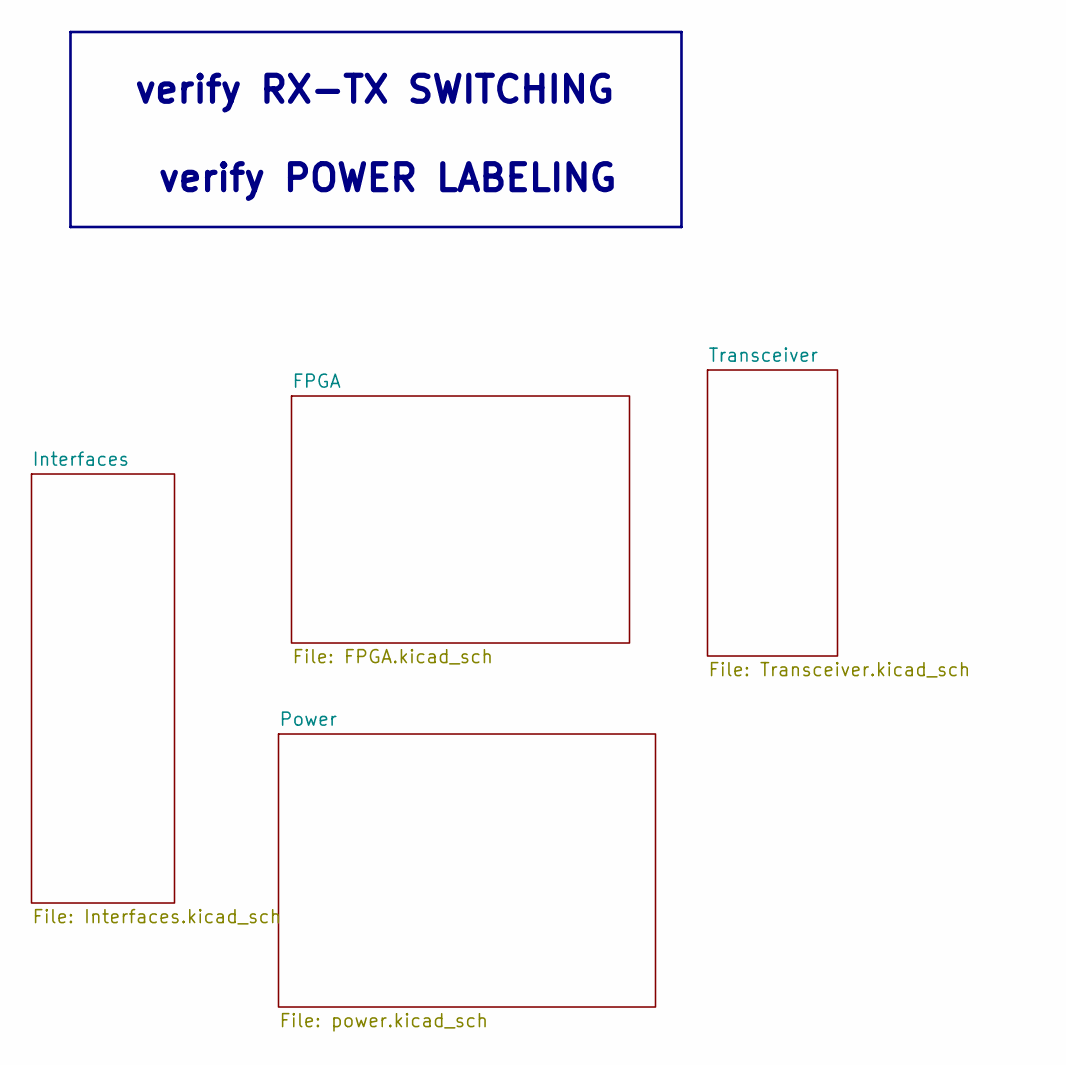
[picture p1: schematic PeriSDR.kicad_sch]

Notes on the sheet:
verify RX-TX SWITCHING
verify POWER LABELING

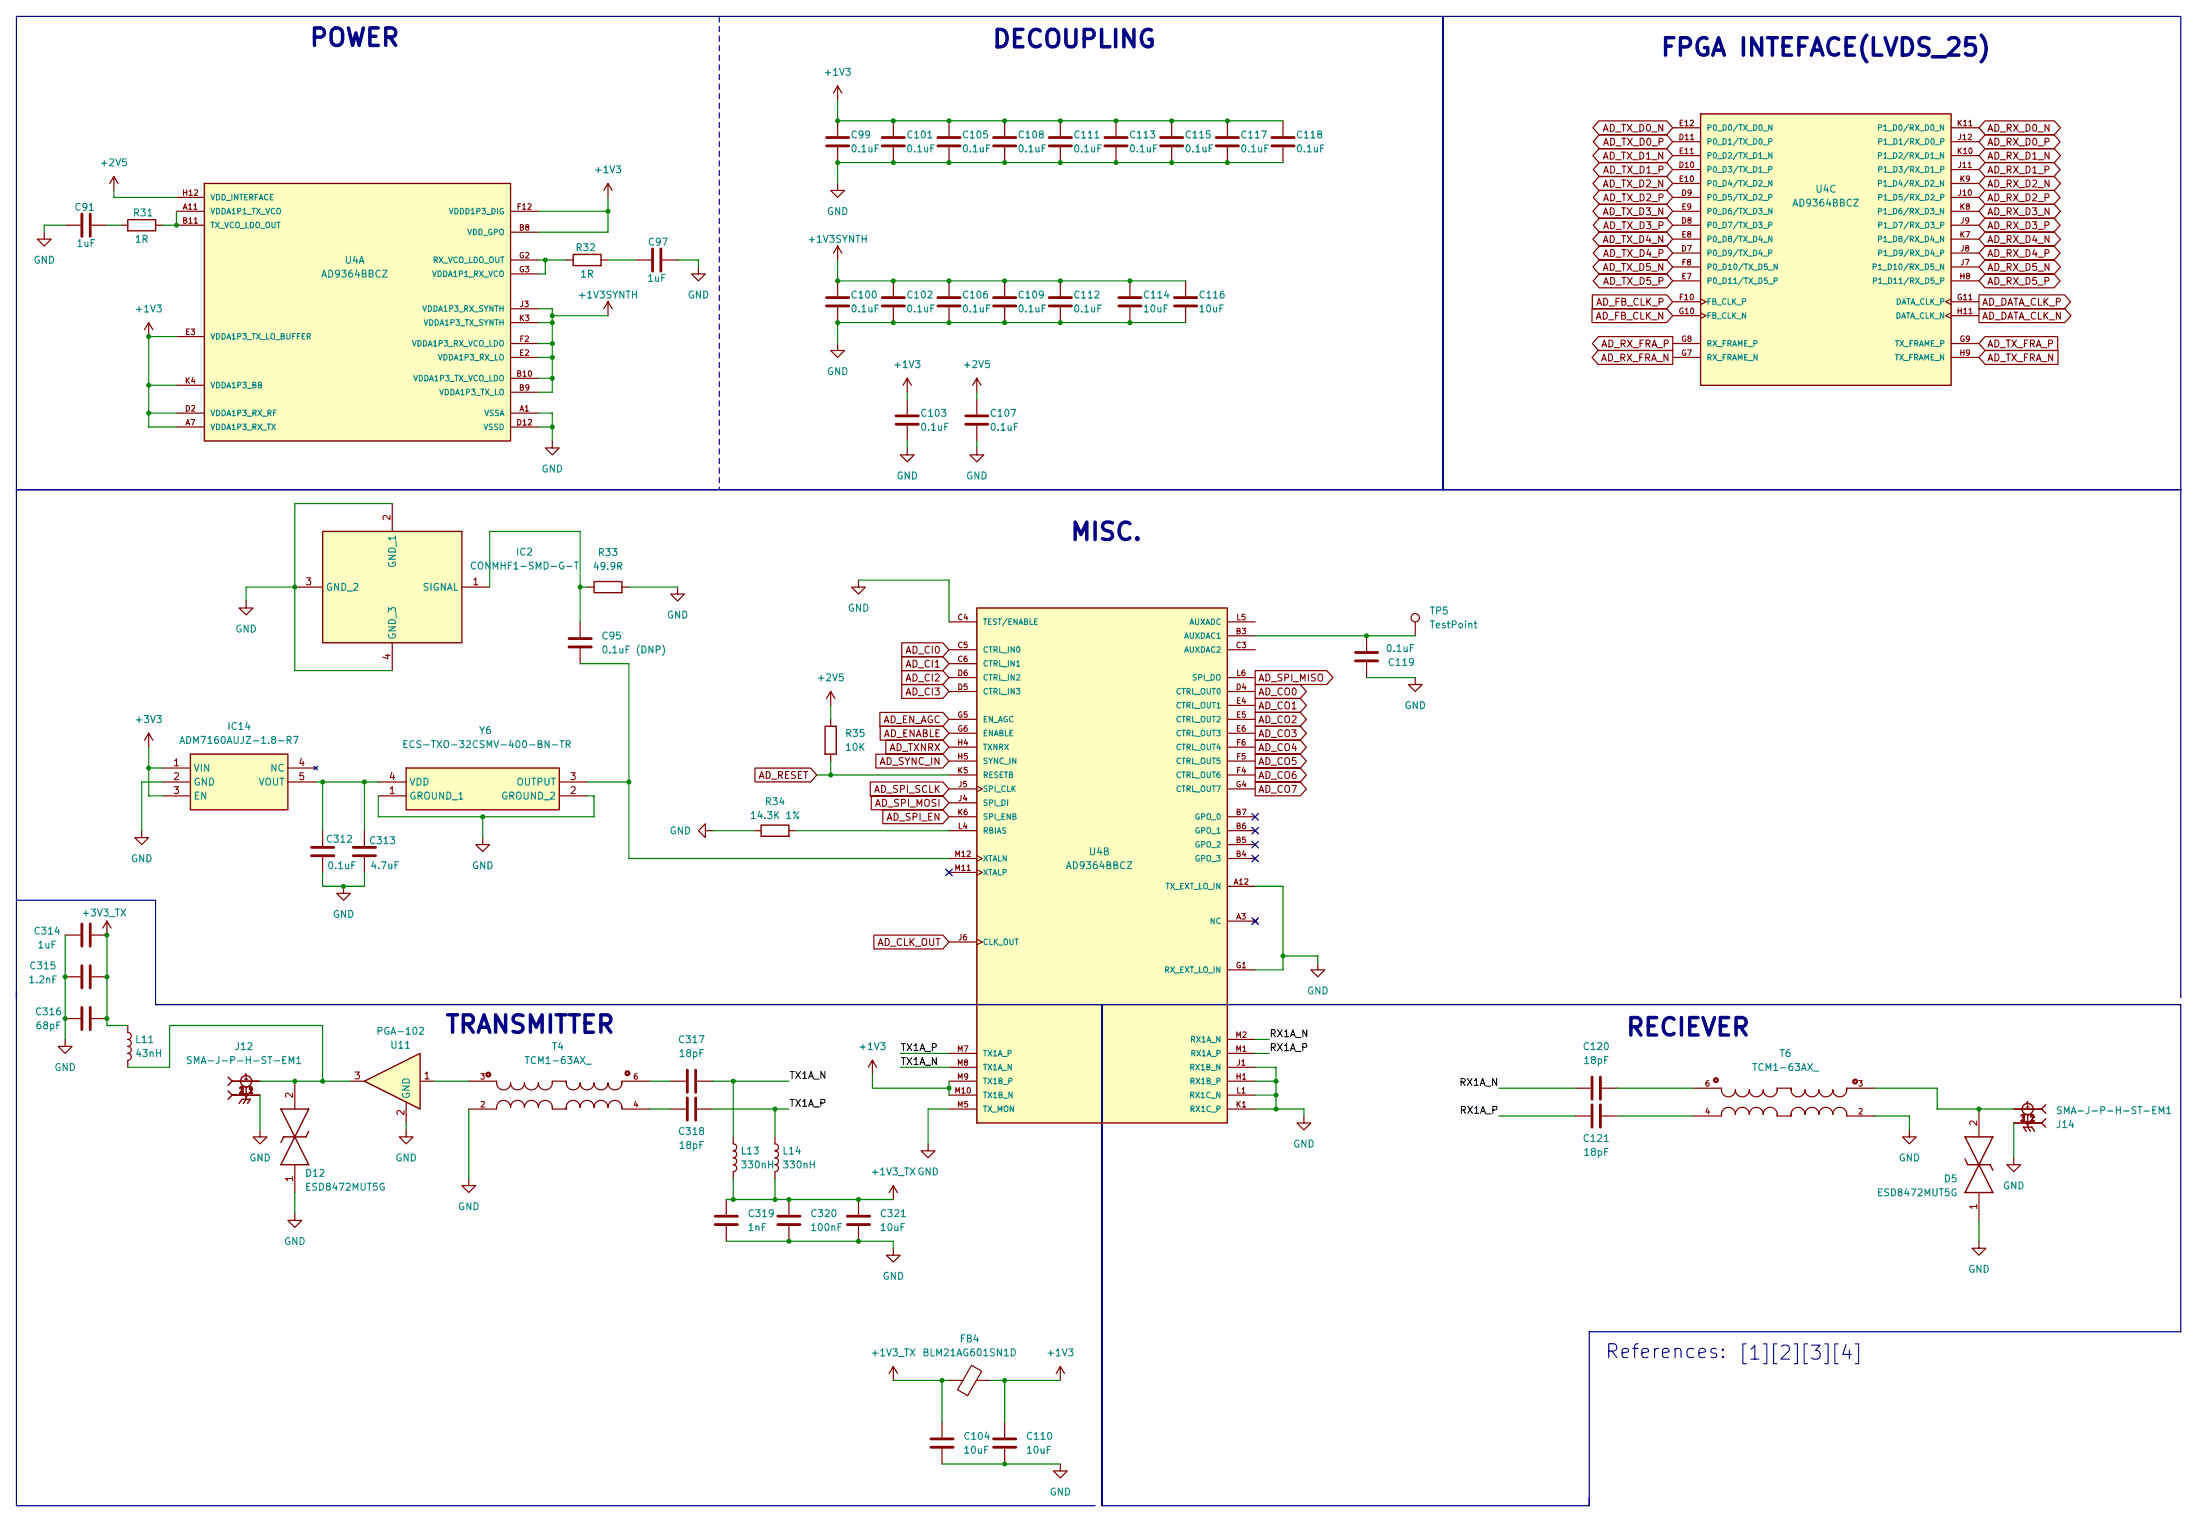
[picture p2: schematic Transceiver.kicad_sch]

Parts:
C91, C97, C314: 1uF; C_0402_1005Metric
C95: 0.1uF (DNP); C_0201_0603Metric
C99, C100, C101, C102, C103, C105, C106, C107, C108, C109, C111, C112, C113, C115, C117, C118, C119, C312: 0.1uF; C_0201_0603Metric
C104, C110, C114, C116, C321: 10uF; C_0603_1608Metric
C120, C121, C317, C318: 18pF; C_0201_0603Metric
C313: 4.7uF; C_0402_1005Metric
C315: 1.2nF; C_0201_0603Metric
C316: 68pF; C_0201_0603Metric
C319: 1nF; C_0201_0603Metric
C320: 100nF; C_0402_1005Metric
D5, D12: ESD8472MUT5G; X3DFN2-CASE152AF-ISSUE-A; Mouser Part Number 863-ESD8472MUT5G
FB4: BLM21AG601SN1D; L_0603_1608Metric
IC2: CONMHF1-SMD-G-T; CONMHF1SMDGT; Manufacturer_Part_Number CONMHF1-SMD-G-T
IC14: ADM7160AUJZ-1.8-R7; SOT95P280X100-5N; Manufacturer_Part_Number ADM7160AUJZ-1.8-R7; Mouser Part Number 584-ADM7160AUJZ1.8R7
J12, J14: SMA-J-P-H-ST-EM1; SAMTEC_SMA-J-P-H-ST-EM1; PARTREV G
L11: 43nH; L_0603_1608Metric
L13, L14: 330nH; L_0603_1608Metric
R31, R32: 1R; R_0402_1005Metric
R33: 49.9R; R_0402_1005Metric
R34: 14.3K 1%; R_0402_1005Metric
R35: 10K; R_0402_1005Metric
T4, T6: TCM1-63AX_; TCM163AX
TP5: TestPoint; TestPoint_Pad_1.0x1.0mm
U4: AD9364BBCZ; BGA144C80P12X12_1000X1000X170N; PARTREV C
U11: PGA-102; SOT-89-3
Y6: ECS-TXO-32CSMV-400-BN-TR; ECSTXO32CSMV400BNTR; Manufacturer_Part_Number ECS-TXO-32CSMV-400-BN-TR; Mouser Part Number 520-TXO32CSMV400BNTR

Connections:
+1V3: C99.1, C101.1, C103.1, C105.1, C108.1, C110.1, C111.1, C113.1, C115.1, C117.1, C118.1, FB4.2, U4.A7 (VDDA1P3_RX_TX), U4.A8 (VDDA1P3_RX_TX), U4.A9 (VDDA1P3_RX_TX), U4.A10 (VDDA1P3_RX_TX), U4.B8 (VDD_GPO), U4.D2 (VDDA1P3_RX_RF), U4.D3 (VDDA1P3_RX_TX), U4.E3 (VDDA1P3_TX_LO_BUFFER), U4.F12 (VDDD1P3_DIG), U4.K4 (VDDA1P3_BB), U4.M9 (TX1B_P), U4.M10 (TX1B_N); also elsewhere on the board
+1V3SYNTH: C100.1, C102.1, C106.1, C109.1, C112.1, C114.1, C116.1, U4.B9 (VDDA1P3_TX_LO), U4.B10 (VDDA1P3_TX_VCO_LDO), U4.E2 (VDDA1P3_RX_LO), U4.F2 (VDDA1P3_RX_VCO_LDO), U4.J3 (VDDA1P3_RX_SYNTH), U4.K3 (VDDA1P3_TX_SYNTH); also elsewhere on the board
+1V3_TX: C104.1, C319.1, C320.1, C321.1, FB4.1, L13.2, L14.2
+2V5: C107.1, R35.1, U4.H12 (VDD_INTERFACE); also elsewhere on the board
+3V3: IC14.1 (VIN), IC14.3 (EN); also elsewhere on the board
+3V3_TX: C314.1, C315.1, C316.1, L11.1; also elsewhere on the board
/Transceiver/RX1A_N: C120.1, U4.M2 (RX1A_N)
/Transceiver/RX1A_P: C121.1, U4.M1 (RX1A_P)
/Transceiver/TX1A_N: C317.1, L13.1, U4.M8 (TX1A_N)
/Transceiver/TX1A_P: C318.1, L14.1, U4.M7 (TX1A_P)
AD_CI0: U4.C5 (CTRL_IN0)
AD_CI1: U4.C6 (CTRL_IN1)
AD_CI2: U4.D6 (CTRL_IN2)
AD_CI3: U4.D5 (CTRL_IN3)
AD_CLK_OUT: U4.J6 (CLK_OUT); also elsewhere on the board
AD_CO0: U4.D4 (CTRL_OUT0)
AD_CO1: U4.E4 (CTRL_OUT1)
AD_CO2: U4.E5 (CTRL_OUT2)
AD_CO3: U4.E6 (CTRL_OUT3)
AD_CO4: U4.F6 (CTRL_OUT4)
AD_CO5: U4.F5 (CTRL_OUT5)
AD_CO6: U4.F4 (CTRL_OUT6)
AD_CO7: U4.G4 (CTRL_OUT7)
AD_DATA_CLK_N: U4.H11 (DATA_CLK_N); also elsewhere on the board
AD_DATA_CLK_P: U4.G11 (DATA_CLK_P); also elsewhere on the board
AD_ENABLE: U4.G6 (ENABLE); also elsewhere on the board
AD_EN_AGC: U4.G5 (EN_AGC); also elsewhere on the board
AD_FB_CLK_N: U4.G10 (FB_CLK_N); also elsewhere on the board
AD_FB_CLK_P: U4.F10 (FB_CLK_P); also elsewhere on the board
AD_RESET: R35.2, U4.K5 (RESETB); also elsewhere on the board
AD_RX_D0_N: U4.K11 (P1_D0/RX_D0_N); also elsewhere on the board
AD_RX_D0_P: U4.J12 (P1_D1/RX_D0_P); also elsewhere on the board
AD_RX_D1_N: U4.K10 (P1_D2/RX_D1_N); also elsewhere on the board
AD_RX_D1_P: U4.J11 (P1_D3/RX_D1_P); also elsewhere on the board
AD_RX_D2_N: U4.K9 (P1_D4/RX_D2_N); also elsewhere on the board
AD_RX_D2_P: U4.J10 (P1_D5/RX_D2_P); also elsewhere on the board
AD_RX_D3_N: U4.K8 (P1_D6/RX_D3_N); also elsewhere on the board
AD_RX_D3_P: U4.J9 (P1_D7/RX_D3_P); also elsewhere on the board
AD_RX_D4_N: U4.K7 (P1_D8/RX_D4_N); also elsewhere on the board
AD_RX_D4_P: U4.J8 (P1_D9/RX_D4_P); also elsewhere on the board
AD_RX_D5_N: U4.J7 (P1_D10/RX_D5_N); also elsewhere on the board
AD_RX_D5_P: U4.H8 (P1_D11/RX_D5_P); also elsewhere on the board
AD_RX_FRA_N: U4.G7 (RX_FRAME_N); also elsewhere on the board
AD_RX_FRA_P: U4.G8 (RX_FRAME_P); also elsewhere on the board
AD_SPI_EN: U4.K6 (SPI_ENB); also elsewhere on the board
AD_SPI_MISO: U4.L6 (SPI_DO); also elsewhere on the board
AD_SPI_MOSI: U4.J4 (SPI_DI); also elsewhere on the board
AD_SPI_SCLK: U4.J5 (SPI_CLK); also elsewhere on the board
AD_SYNC_IN: U4.H5 (SYNC_IN); also elsewhere on the board
AD_TXNRX: U4.H4 (TXNRX); also elsewhere on the board
AD_TX_D0_N: U4.E12 (P0_D0/TX_D0_N); also elsewhere on the board
AD_TX_D0_P: U4.D11 (P0_D1/TX_D0_P); also elsewhere on the board
AD_TX_D1_N: U4.E11 (P0_D2/TX_D1_N); also elsewhere on the board
AD_TX_D1_P: U4.D10 (P0_D3/TX_D1_P); also elsewhere on the board
AD_TX_D2_N: U4.E10 (P0_D4/TX_D2_N); also elsewhere on the board
AD_TX_D2_P: U4.D9 (P0_D5/TX_D2_P); also elsewhere on the board
AD_TX_D3_N: U4.E9 (P0_D6/TX_D3_N); also elsewhere on the board
AD_TX_D3_P: U4.D8 (P0_D7/TX_D3_P); also elsewhere on the board
AD_TX_D4_N: U4.E8 (P0_D8/TX_D4_N); also elsewhere on the board
AD_TX_D4_P: U4.D7 (P0_D9/TX_D4_P); also elsewhere on the board
AD_TX_D5_N: U4.F8 (P0_D10/TX_D5_N); also elsewhere on the board
AD_TX_D5_P: U4.E7 (P0_D11/TX_D5_P); also elsewhere on the board
AD_TX_FRA_N: U4.H9 (TX_FRAME_N); also elsewhere on the board
AD_TX_FRA_P: U4.G9 (TX_FRAME_P); also elsewhere on the board
GND: C91.2, C97.2, C99.2, C100.2, C101.2, C102.2, C103.2, C104.2, C105.2, C106.2, C107.2, C108.2, C109.2, C110.2, C111.2, C112.2, C113.2, C114.2, C115.2, C116.2, C117.2, C118.2, C119.1, C312.2, C313.2, C314.2, C315.2, C316.2, C319.2, C320.2, C321.2, D5.1, D12.1, IC2.2 (GND_1), IC2.3 (GND_2), IC2.4 (GND_3), IC14.2 (GND), J12.2_1, J12.2_2, J12.3_1, J12.3_2, J14.2_1, J14.2_2, J14.3_1, J14.3_2, R33.2, R34.1, T4.2, T6.2, U4.A1 (VSSA), U4.A2 (VSSA), U4.A4 (VSSA), U4.A5 (VSSA), U4.A6 (VSSA), U4.A12 (TX_EXT_LO_IN), U4.B1 (VSSA), U4.B2 (VSSA), U4.B12 (VSSA), U4.C1 (VSSA), U4.C2 (VSSA), U4.C4 (TEST/ENABLE), U4.C7 (VSSA), U4.C8 (VSSA), U4.C9 (VSSA), U4.C10 (VSSA), U4.C11 (VSSA), U4.C12 (VSSA), U4.D1 (VSSA), U4.D12 (VSSD), U4.E1 (VSSA), U4.F1 (VSSA), U4.F3 (VSSA), U4.F7 (VSSD), U4.F9 (VSSD), U4.F11 (VSSD), U4.G1 (RX_EXT_LO_IN), U4.G12 (VSSD), U4.H1 (RX1B_P), U4.H2 (VSSA), U4.H3 (VSSA), U4.H6 (VSSA), U4.H7 (VSSD), U4.H10 (VSSD), U4.J1 (RX1B_N), U4.J2 (VSSA), U4.K1 (RX1C_P), U4.K2 (VSSA), U4.K12 (VSSD), U4.L1 (RX1C_N), U4.L2 (VSSA), U4.L3 (VSSA), U4.L7 (VSSA), U4.L8 (VSSA), U4.L9 (VSSA), U4.L10 (VSSA), U4.L11 (VSSA), U4.L12 (VSSA), U4.M3 (NC), U4.M4 (VSSA), U4.M5 (TX_MON), U4.M6 (VSSA), U11.2 (GND_2), Y6.1 (GROUND_1), Y6.2 (GROUND_2); also elsewhere on the board
unnamed: C91.1, R31.2
unnamed: C97.1, R32.2
unnamed: C120.2, T6.6
unnamed: C121.2, T6.4
unnamed: C317.2, T4.6
unnamed: C318.2, T4.4
unnamed: D5.2, J14.1, T6.3
unnamed: D12.2, J12.1, L11.2, U11.3
unnamed: C95.1, IC2.1 (SIGNAL), R33.1
unnamed: C312.1, C313.1, IC14.5 (VOUT), Y6.4 (VDD)
unnamed: T4.3, U11.1
unnamed: R32.1, U4.G2 (RX_VCO_LDO_OUT), U4.G3 (VDDA1P1_RX_VCO)
unnamed: R31.1, U4.A11 (VDDA1P1_TX_VCO), U4.B11 (TX_VCO_LDO_OUT)
unnamed: C119.2, TP5.1 (1_1), U4.B3 (AUXDAC1)
unnamed: R34.2, U4.L4 (RBIAS)
unnamed: C95.2, U4.M12 (XTALN), Y6.3 (OUTPUT)

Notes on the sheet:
FPGA INTEFACE(LVDS_25)
TRANSMITTER
[2]
RECIEVER
MISC.
References:
[3]
[4]
POWER
DECOUPLING
[1]

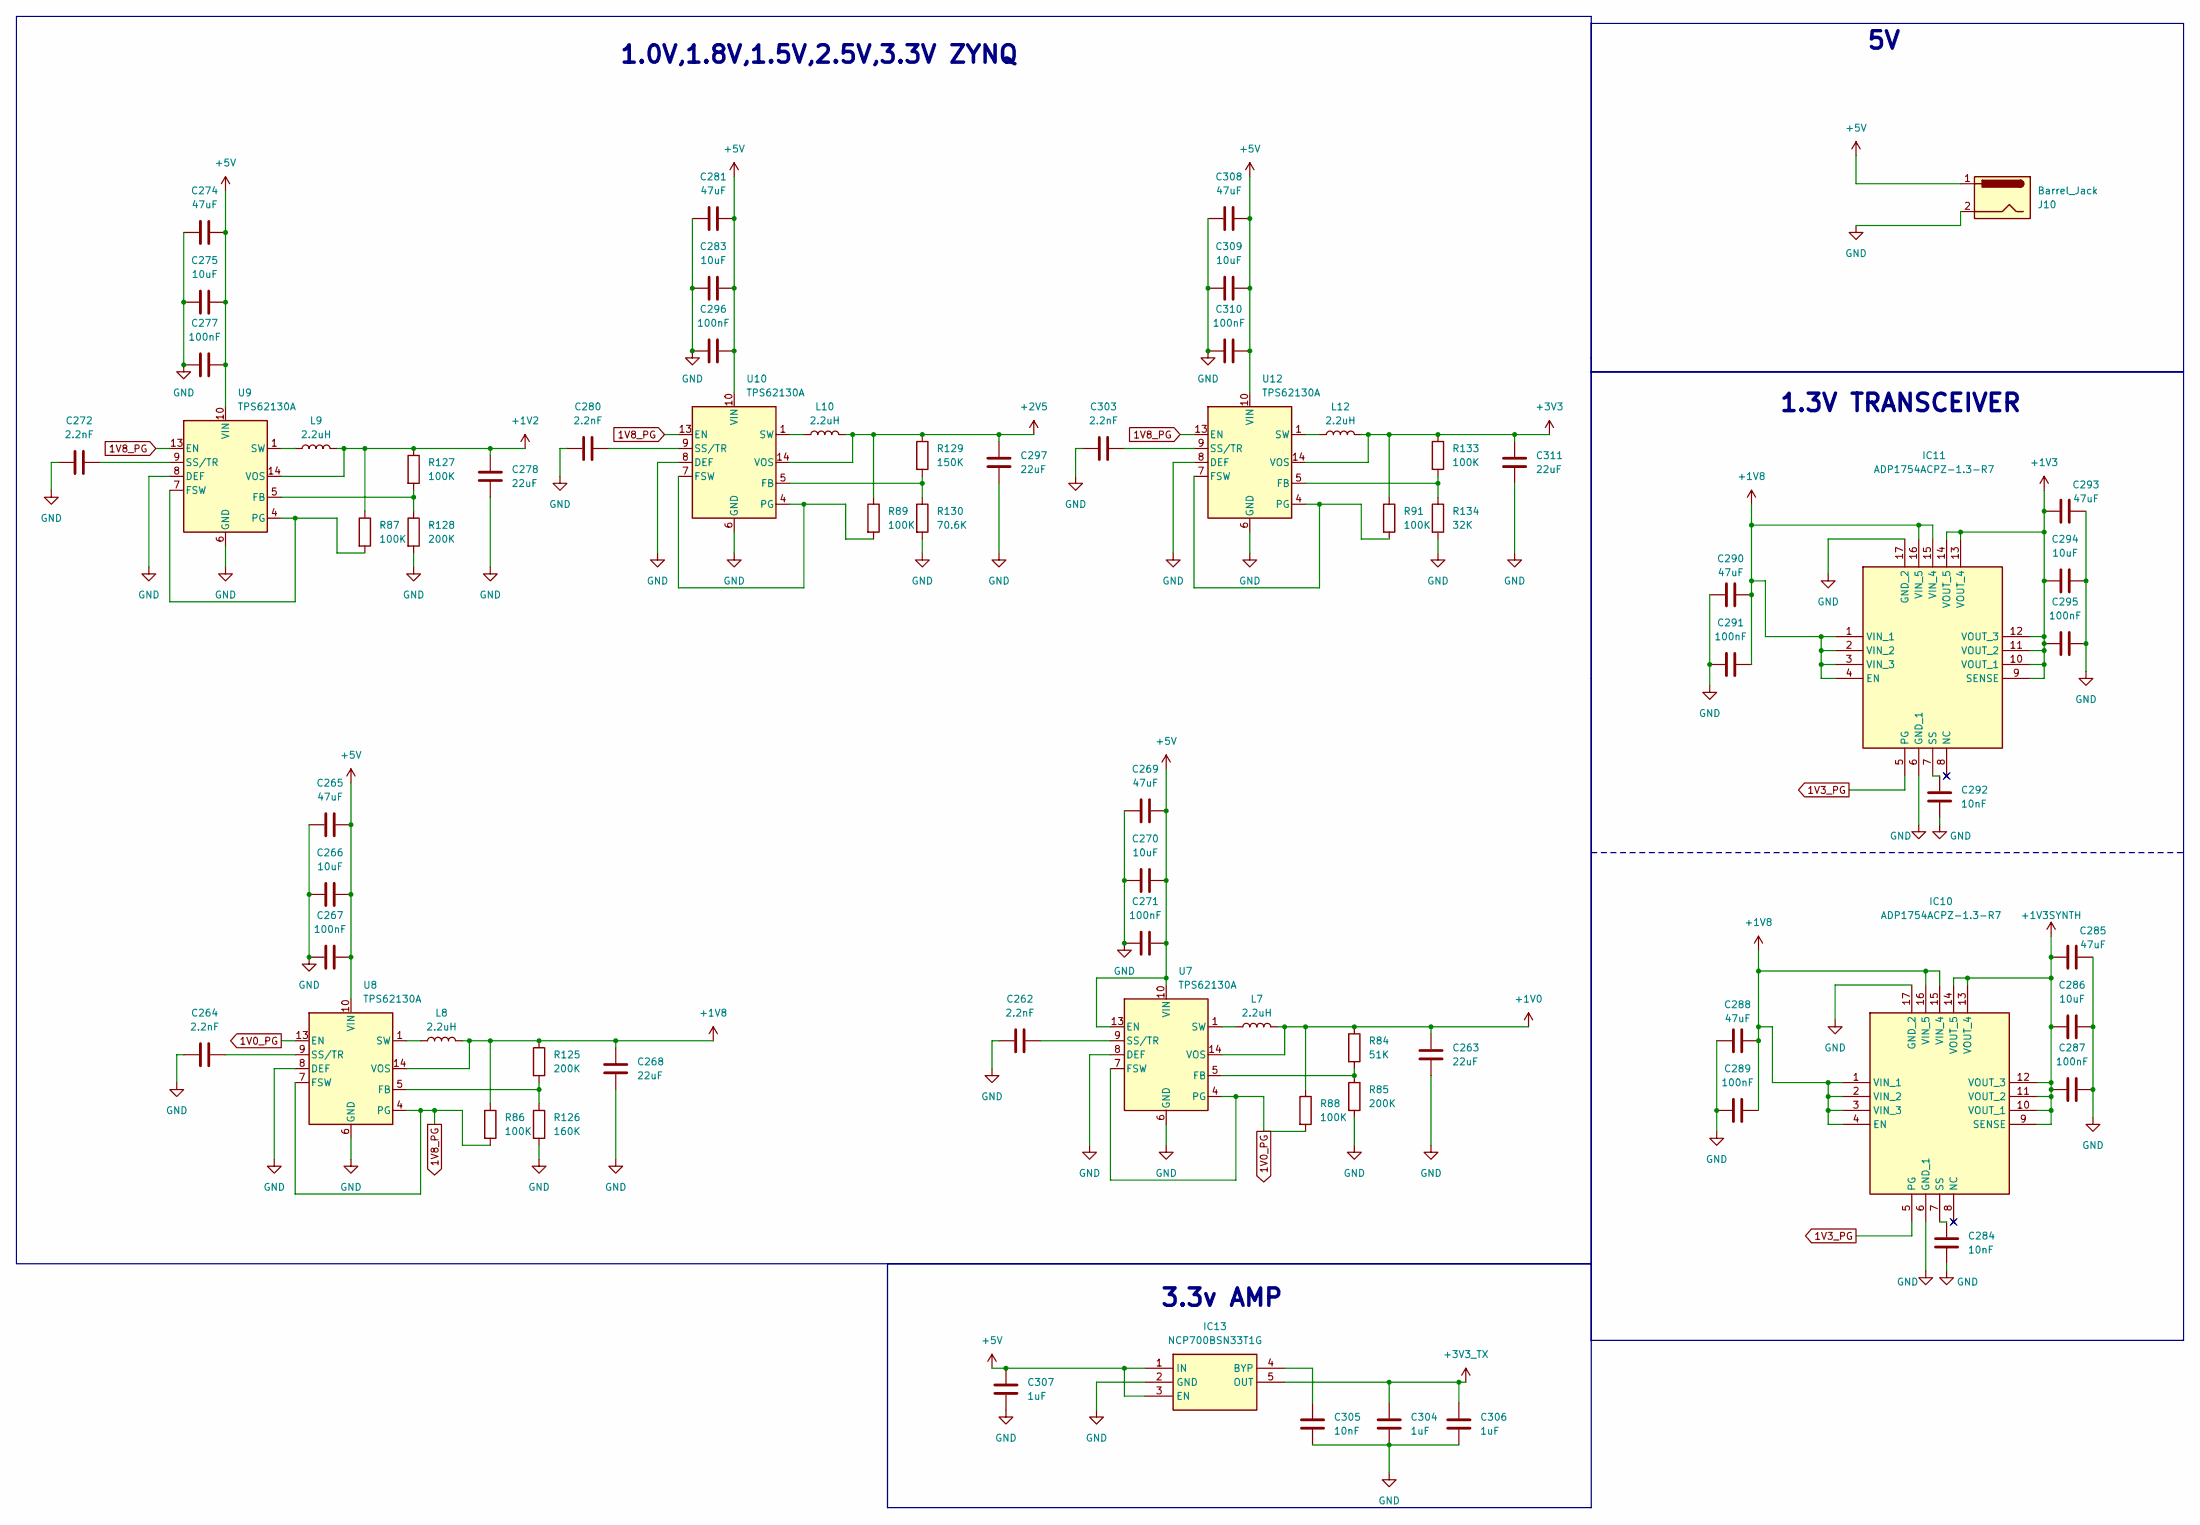
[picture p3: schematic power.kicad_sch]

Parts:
C262, C264, C272, C280, C303: 2.2nF; C_0201_0603Metric
C263, C268, C278, C297: 22uF; C_0603_1608Metric
C265, C269, C274, C281, C285, C288, C290, C293, C308: 47uF; C_0603_1608Metric
C266, C270, C275, C283, C286, C294, C309: 10uF; C_0603_1608Metric
C267, C271, C277, C287, C289, C291, C295, C296, C310: 100nF; C_0402_1005Metric
C284, C292, C305: 10nF; C_0201_0603Metric
C304, C306, C307: 1uF; C_0402_1005Metric
C311: 22uF; C_0805_2012Metric
IC10, IC11: ADP1754ACPZ-1.3-R7; QFN65P400X400X80-17N-D; Manufacturer_Part_Number ADP1754ACPZ-1.3-R7; Mouser Part Number 584-P1754ACPZ13R7
IC13: NCP700BSN33T1G; SOT95P275X110-5N; Manufacturer_Part_Number NCP700BSN33T1G; Mouser Part Number 863-NCP700BSN33T1G
J10: Barrel_Jack; BarrelJack_CUI_PJ-063AH_Horizontal
L7, L8, L9, L10, L12: 2.2uH; XFL4020-222ME
R84: 51K; R_0402_1005Metric
R85, R125, R128: 200K; R_0402_1005Metric
R86, R87, R88, R89, R91, R127, R133: 100K; R_0402_1005Metric
R126: 160K; R_0402_1005Metric
R129: 150K; R_0402_1005Metric
R130: 70.6K; R_0402_1005Metric
R134: 32K; R_0402_1005Metric
U7, U8, U9, U10, U12: TPS62130A; VQFN-16-1EP_3x3mm_P0.5mm_EP1.68x1.68mm_ThermalVias

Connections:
1V0_PG: R88.2, U7.4 (PG), U7.7 (FSW), U8.13 (EN)
1V3_PG: IC10.5 (PG), IC11.5 (PG)
1V8_PG: R86.2, U8.4 (PG), U8.7 (FSW), U9.13 (EN), U10.13 (EN), U12.13 (EN)
+1V0: C263.1, L7.2, R84.1, R88.1, U7.14 (VOS); also elsewhere on the board
+1V2: C278.1, L9.2, R87.1, R127.1, U9.14 (VOS); also elsewhere on the board
+1V3: C293.1, C294.1, C295.1, IC11.9 (SENSE), IC11.10 (VOUT_1), IC11.11 (VOUT_2), IC11.12 (VOUT_3), IC11.13 (VOUT_4), IC11.14 (VOUT_5); also elsewhere on the board
+1V3SYNTH: C285.1, C286.1, C287.1, IC10.9 (SENSE), IC10.10 (VOUT_1), IC10.11 (VOUT_2), IC10.12 (VOUT_3), IC10.13 (VOUT_4), IC10.14 (VOUT_5); also elsewhere on the board
+1V8: C268.1, C288.2, C289.2, C290.2, C291.2, IC10.1 (VIN_1), IC10.2 (VIN_2), IC10.3 (VIN_3), IC10.4 (EN), IC10.15 (VIN_4), IC10.16 (VIN_5), IC11.1 (VIN_1), IC11.2 (VIN_2), IC11.3 (VIN_3), IC11.4 (EN), IC11.15 (VIN_4), IC11.16 (VIN_5), L8.2, R86.1, R125.1, U8.14 (VOS); also elsewhere on the board
+2V5: C297.1, L10.2, R89.1, R129.1, U10.14 (VOS); also elsewhere on the board
+3V3: C311.1, L12.2, R91.1, R133.1, U12.14 (VOS); also elsewhere on the board
+3V3_TX: C304.1, C306.1, IC13.5 (OUT); also elsewhere on the board
+5V: C265.2, C266.2, C267.2, C269.2, C270.2, C271.2, C274.2, C275.2, C277.2, C281.2, C283.2, C296.2, C307.1, C308.2, C309.2, C310.2, IC13.1 (IN), IC13.3 (EN), J10.1, U7.10 (VIN), U7.11 (VIN), U7.12 (VIN), U7.13 (EN), U8.10 (VIN), U8.11 (VIN), U8.12 (VIN), U9.10 (VIN), U9.11 (VIN), U9.12 (VIN), U10.10 (VIN), U10.11 (VIN), U10.12 (VIN), U12.10 (VIN), U12.11 (VIN), U12.12 (VIN); also elsewhere on the board
GND: C262.1, C263.2, C264.1, C265.1, C266.1, C267.1, C268.2, C269.1, C270.1, C271.1, C272.1, C274.1, C275.1, C277.1, C278.2, C280.1, C281.1, C283.1, C284.1, C285.2, C286.2, C287.2, C288.1, C289.1, C290.1, C291.1, C292.1, C293.2, C294.2, C295.2, C296.1, C297.2, C303.1, C304.2, C305.2, C306.2, C307.2, C308.1, C309.1, C310.1, C311.2, IC10.6 (GND_1), IC10.17 (GND_2), IC11.6 (GND_1), IC11.17 (GND_2), IC13.2 (GND), J10.2, R85.2, R126.2, R128.2, R130.2, R134.2, U7.6 (GND), U7.8 (DEF), U7.15 (GND), U7.16 (GND), U7.17 (GND), U8.6 (GND), U8.8 (DEF), U8.15 (GND), U8.16 (GND), U8.17 (GND), U9.6 (GND), U9.8 (DEF), U9.15 (GND), U9.16 (GND), U9.17 (GND), U10.6 (GND), U10.8 (DEF), U10.15 (GND), U10.16 (GND), U10.17 (GND), U12.6 (GND), U12.8 (DEF), U12.15 (GND), U12.16 (GND), U12.17 (GND); also elsewhere on the board
unnamed: C284.2, IC10.7 (SS)
unnamed: C292.2, IC11.7 (SS)
unnamed: C305.1, IC13.4 (BYP)
unnamed: L7.1, U7.1 (SW), U7.2 (SW), U7.3 (SW)
unnamed: L8.1, U8.1 (SW), U8.2 (SW), U8.3 (SW)
unnamed: L9.1, U9.1 (SW), U9.2 (SW), U9.3 (SW)
unnamed: L10.1, U10.1 (SW), U10.2 (SW), U10.3 (SW)
unnamed: L12.1, U12.1 (SW), U12.2 (SW), U12.3 (SW)
unnamed: R84.2, R85.1, U7.5 (FB)
unnamed: C262.2, U7.9 (SS/TR)
unnamed: R125.2, R126.1, U8.5 (FB)
unnamed: C264.2, U8.9 (SS/TR)
unnamed: R127.2, R128.1, U9.5 (FB)
unnamed: R87.2, U9.4 (PG), U9.7 (FSW)
unnamed: C272.2, U9.9 (SS/TR)
unnamed: R129.2, R130.1, U10.5 (FB)
unnamed: R89.2, U10.4 (PG), U10.7 (FSW)
unnamed: C280.2, U10.9 (SS/TR)
unnamed: R133.2, R134.1, U12.5 (FB)
unnamed: R91.2, U12.4 (PG), U12.7 (FSW)
unnamed: C303.2, U12.9 (SS/TR)

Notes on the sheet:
3.3v AMP
1.0V,1.8V,1.5V,2.5V,3.3V ZYNQ
1.3V TRANSCEIVER

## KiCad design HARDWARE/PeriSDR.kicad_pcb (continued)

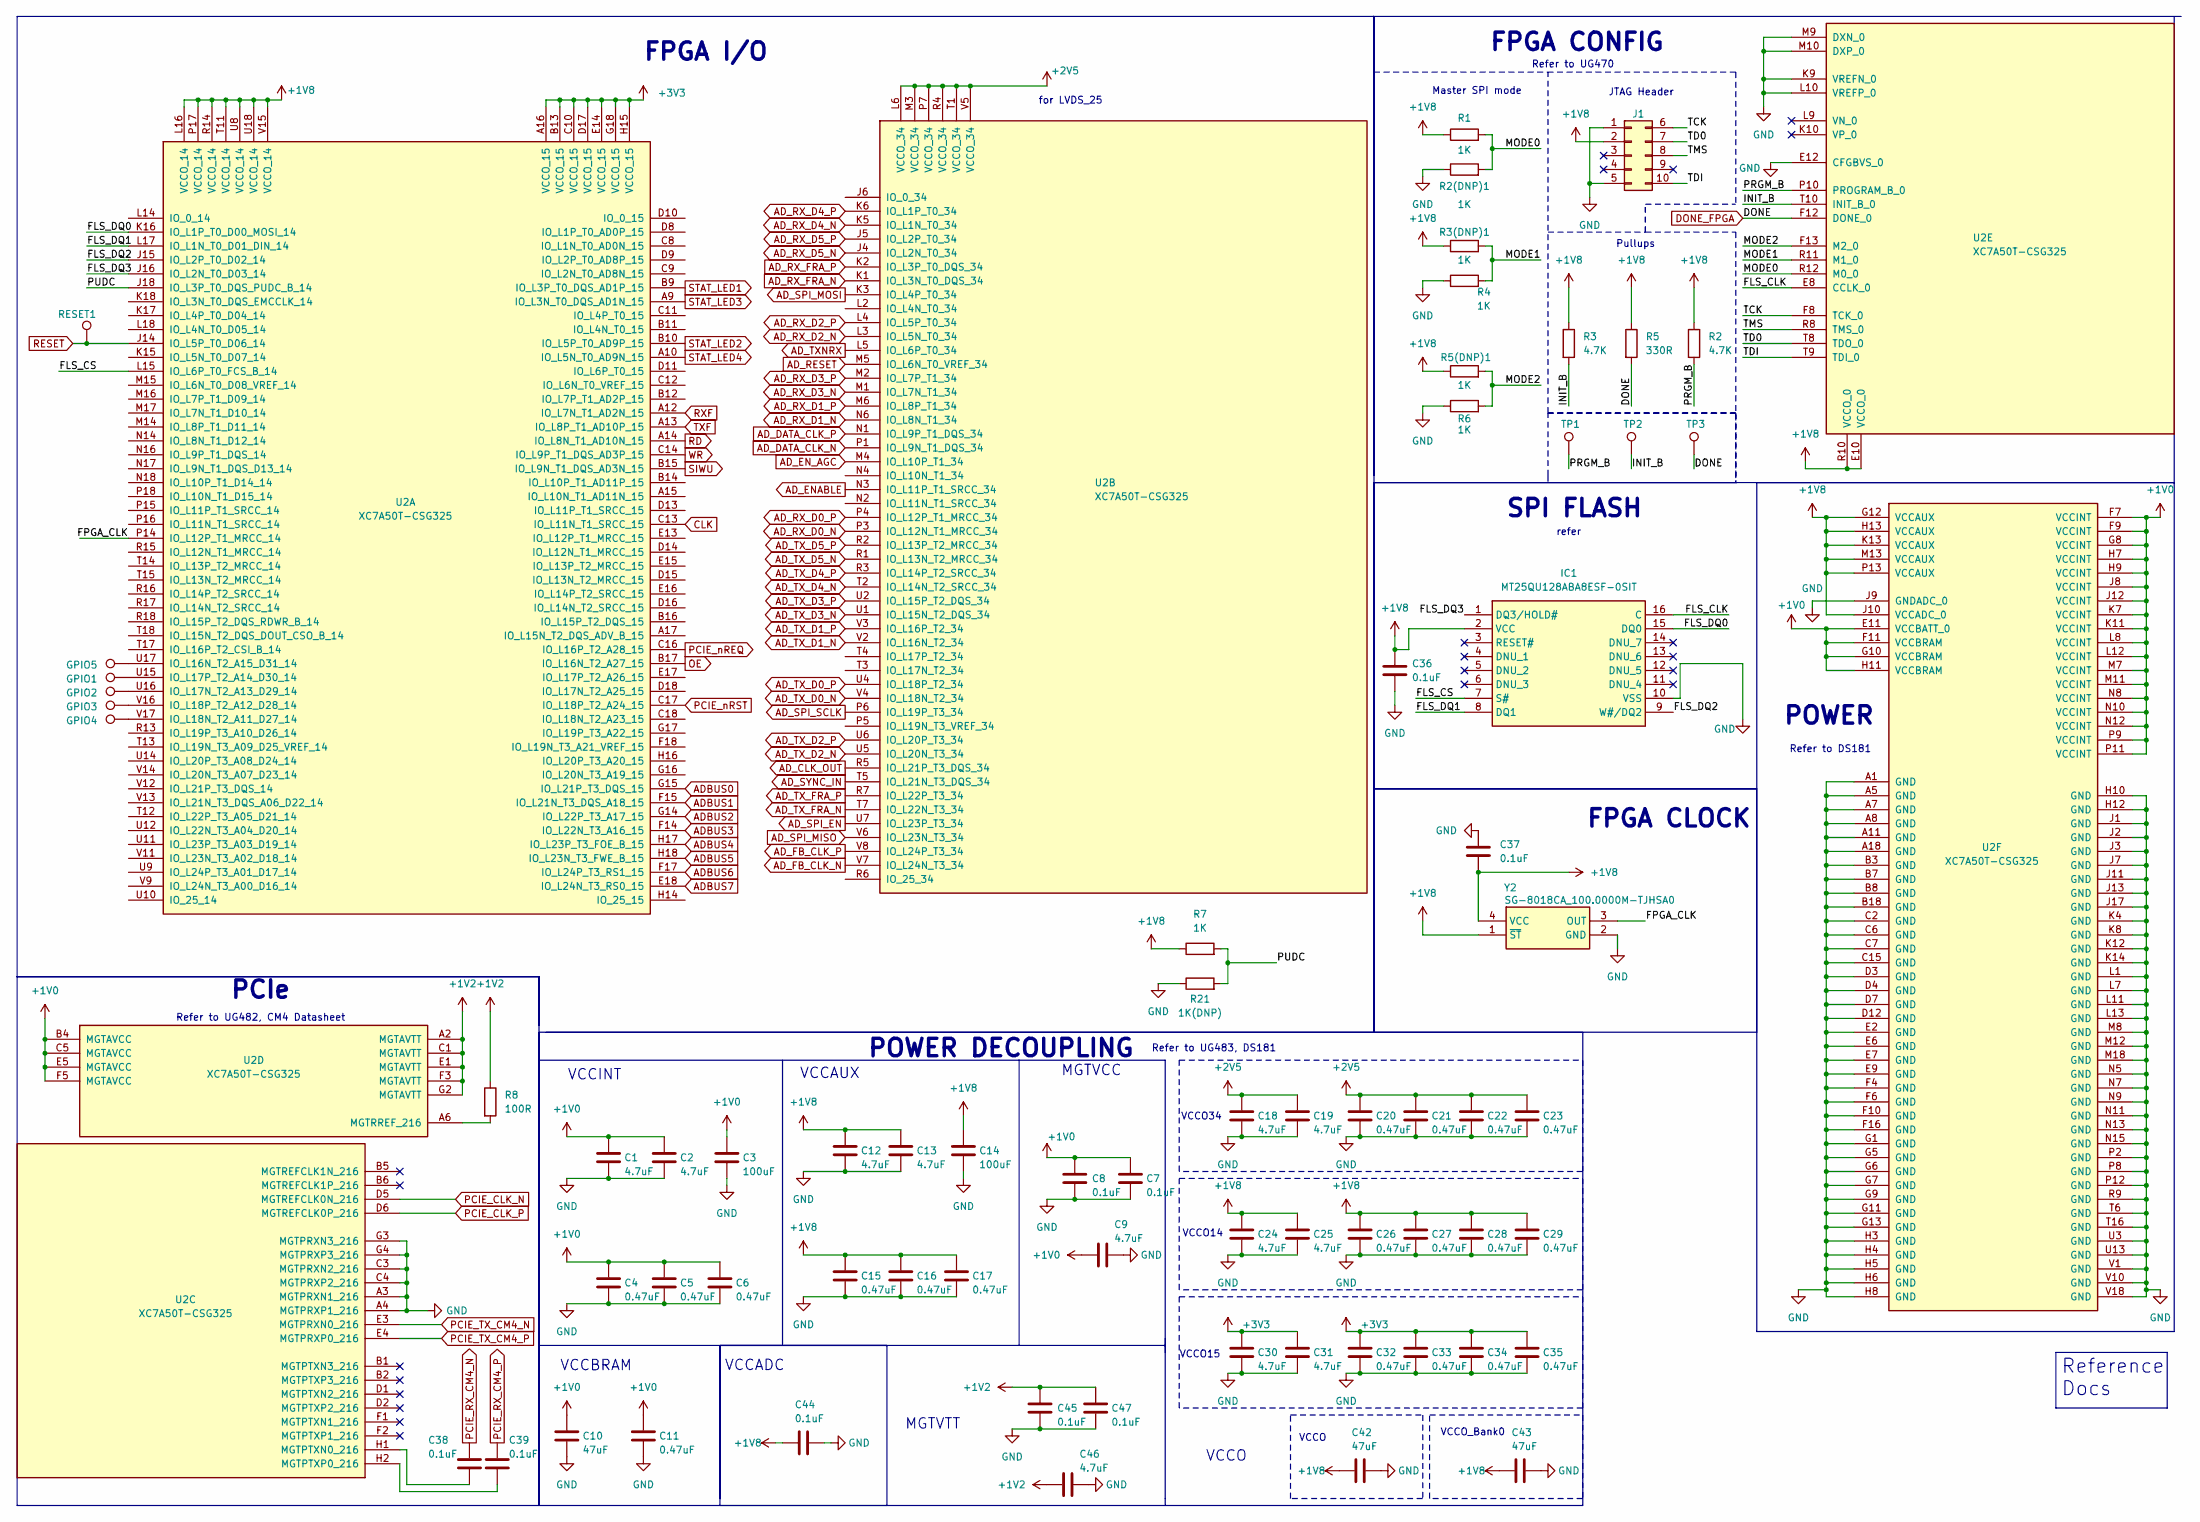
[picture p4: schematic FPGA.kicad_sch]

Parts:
C1, C2, C9, C12, C13, C18, C19, C24, C25, C30, C31, C46: 4.7uF; C_0402_1005Metric
C3, C14: 100uF; C_0805_2012Metric
C4, C5, C6, C11, C15, C16, C17, C20, C21, C22, C23, C26, C27, C28, C29, C32, C33, C34, C35: 0.47uF; C_0402_1005Metric
C7, C8, C36, C37, C38, C39, C44, C45, C47: 0.1uF; C_0402_1005Metric
C10, C42, C43: 47uF; C_0603_1608Metric
GPIO1, GPIO2, GPIO3, GPIO4, GPIO5: TestPoint; TestPoint_Pad_1.0x1.0mm
IC1: MT25QU128ABA8ESF-0SIT; SOIC127P1032X265-16N; Mouser Part Number 340-283176-TRAY
J1: Conn_02x05_Top_Bottom; PinHeader_2x05_P2.54mm_Vertical
R1, R2(DNP)1, R3(DNP)1, R4, R5(DNP)1, R6, R7: 1K; R_0402_1005Metric
R2, R3: 4.7K; R_0402_1005Metric
R5: 330R; R_0402_1005Metric
R8: 100R; R_0402_1005Metric
R21: 1K(DNP); R_0402_1005Metric
RESET1: TestPoint; TestPoint_Pad_1.0x1.0mm
TP1, TP2, TP3: TestPoint; TestPoint_Pad_1.0x1.0mm
U2: XC7A50T-CSG325; Xilinx_CSG325
Y2: SG-8018CA_100.0000M-TJHSA0; SG8018CA1000000MTJHSA0; Manufacturer_Part_Number SG-8018CA 100.0000M-TJHSA0

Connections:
+1V0: C1.1, C2.1, C3.1, C4.1, C5.1, C6.1, C7.1, C8.1, C9.1, C10.1, C11.1, U2.B4 (MGTAVCC), U2.C5 (MGTAVCC), U2.E5 (MGTAVCC), U2.E11 (VCCBATT_0), U2.F5 (MGTAVCC), U2.F7 (VCCINT), U2.F9 (VCCINT), U2.F11 (VCCBRAM), U2.G8 (VCCINT), U2.G10 (VCCBRAM), U2.H7 (VCCINT), U2.H9 (VCCINT), U2.H11 (VCCBRAM), U2.J8 (VCCINT), U2.J12 (VCCINT), U2.K7 (VCCINT), U2.K11 (VCCINT), U2.L8 (VCCINT), U2.L12 (VCCINT), U2.M7 (VCCINT), U2.M11 (VCCINT), U2.N8 (VCCINT), U2.N10 (VCCINT), U2.N12 (VCCINT), U2.P9 (VCCINT), U2.P11 (VCCINT); also elsewhere on the board
+1V2: C45.1, C46.1, C47.1, R8.1, U2.A2 (MGTAVTT), U2.C1 (MGTAVTT), U2.E1 (MGTAVTT), U2.F3 (MGTAVTT), U2.G2 (MGTAVTT); also elsewhere on the board
+1V8: C12.1, C13.1, C14.1, C15.1, C16.1, C17.1, C24.1, C25.1, C26.1, C27.1, C28.1, C29.1, C36.1, C37.1, C42.1, C43.1, C44.1, IC1.2 (VCC), J1.2, R1.1, R2.1, R3.1, R3(DNP)1.1, R5.1, R5(DNP)1.1, R7.1, U2.E10 (VCCO_0), U2.G12 (VCCAUX), U2.H13 (VCCAUX), U2.J10 (VCCADC_0), U2.K13 (VCCAUX), U2.L16 (VCCO_14), U2.M13 (VCCAUX), U2.P13 (VCCAUX), U2.P17 (VCCO_14), U2.R10 (VCCO_0), U2.R14 (VCCO_14), U2.T11 (VCCO_14), U2.U8 (VCCO_14), U2.U18 (VCCO_14), U2.V15 (VCCO_14), Y2.1 (~ST), Y2.4 (VCC); also elsewhere on the board
+2V5: C18.1, C19.1, C20.1, C21.1, C22.1, C23.1, U2.L6 (VCCO_34), U2.M3 (VCCO_34), U2.P7 (VCCO_34), U2.R4 (VCCO_34), U2.T1 (VCCO_34), U2.V5 (VCCO_34); also elsewhere on the board
+3V3: C30.1, C31.1, C32.1, C33.1, C34.1, C35.1, U2.A16 (VCCO_15), U2.B13 (VCCO_15), U2.C10 (VCCO_15), U2.D17 (VCCO_15), U2.E14 (VCCO_15), U2.G18 (VCCO_15), U2.H15 (VCCO_15); also elsewhere on the board
/FPGA/FLS_CLK: IC1.16 (C), U2.E8 (CCLK_0)
/FPGA/FLS_CS: IC1.7 (S#), U2.L15 (IO_L6P_T0_FCS_B_14)
/FPGA/FLS_DQ0: IC1.15 (DQ0), U2.K16 (IO_L1P_T0_D00_MOSI_14)
/FPGA/FLS_DQ1: IC1.8 (DQ1), U2.L17 (IO_L1N_T0_D01_DIN_14)
/FPGA/FLS_DQ2: IC1.9 (W#/DQ2), U2.J15 (IO_L2P_T0_D02_14)
/FPGA/FLS_DQ3: IC1.1 (DQ3/HOLD#), U2.J16 (IO_L2N_T0_D03_14)
/FPGA/FPGA_CLK: U2.P14 (IO_L12P_T1_MRCC_14), Y2.3 (OUT)
/FPGA/INIT_B: R3.2, TP2.1 (1_1), U2.T10 (INIT_B_0)
/FPGA/MODE0: R1.2, R2(DNP)1.2, U2.R12 (M0_0)
/FPGA/MODE1: R3(DNP)1.2, R4.2, U2.R11 (M1_0)
/FPGA/MODE2: R5(DNP)1.2, R6.2, U2.F13 (M2_0)
/FPGA/PRGM_B: R2.2, TP1.1 (1_1), U2.P10 (PROGRAM_B_0)
/FPGA/PUDC: R7.2, R21.2, U2.J18 (IO_L3P_T0_DQS_PUDC_B_14)
/FPGA/TCK: J1.6, U2.F8 (TCK_0)
/FPGA/TD0: J1.7, U2.T8 (TDO_0)
/FPGA/TDI: J1.10, U2.T9 (TDI_0)
/FPGA/TMS: J1.8, U2.R8 (TMS_0)
ADBUS0: U2.G15 (IO_L21P_T3_DQS_15); also elsewhere on the board
ADBUS1: U2.F15 (IO_L21N_T3_DQS_A18_15); also elsewhere on the board
ADBUS2: U2.G14 (IO_L22P_T3_A17_15); also elsewhere on the board
ADBUS3: U2.F14 (IO_L22N_T3_A16_15); also elsewhere on the board
ADBUS4: U2.H17 (IO_L23P_T3_FOE_B_15); also elsewhere on the board
ADBUS5: U2.H18 (IO_L23N_T3_FWE_B_15); also elsewhere on the board
ADBUS6: U2.F17 (IO_L24P_T3_RS1_15); also elsewhere on the board
ADBUS7: U2.E18 (IO_L24N_T3_RS0_15); also elsewhere on the board
AD_CLK_OUT: U2.R5 (IO_L21P_T3_DQS_34); also elsewhere on the board
AD_DATA_CLK_N: U2.P1 (IO_L9N_T1_DQS_34); also elsewhere on the board
AD_DATA_CLK_P: U2.N1 (IO_L9P_T1_DQS_34); also elsewhere on the board
AD_ENABLE: U2.N3 (IO_L11P_T1_SRCC_34); also elsewhere on the board
AD_EN_AGC: U2.M4 (IO_L10P_T1_34); also elsewhere on the board
AD_FB_CLK_N: U2.V7 (IO_L24N_T3_34); also elsewhere on the board
AD_FB_CLK_P: U2.V8 (IO_L24P_T3_34); also elsewhere on the board
AD_RESET: U2.M5 (IO_L6N_T0_VREF_34); also elsewhere on the board
AD_RX_D0_N: U2.P3 (IO_L12N_T1_MRCC_34); also elsewhere on the board
AD_RX_D0_P: U2.P4 (IO_L12P_T1_MRCC_34); also elsewhere on the board
AD_RX_D1_N: U2.N6 (IO_L8N_T1_34); also elsewhere on the board
AD_RX_D1_P: U2.M6 (IO_L8P_T1_34); also elsewhere on the board
AD_RX_D2_N: U2.L3 (IO_L5N_T0_34); also elsewhere on the board
AD_RX_D2_P: U2.L4 (IO_L5P_T0_34); also elsewhere on the board
AD_RX_D3_N: U2.M1 (IO_L7N_T1_34); also elsewhere on the board
AD_RX_D3_P: U2.M2 (IO_L7P_T1_34); also elsewhere on the board
AD_RX_D4_N: U2.K5 (IO_L1N_T0_34); also elsewhere on the board
AD_RX_D4_P: U2.K6 (IO_L1P_T0_34); also elsewhere on the board
AD_RX_D5_N: U2.J4 (IO_L2N_T0_34); also elsewhere on the board
AD_RX_D5_P: U2.J5 (IO_L2P_T0_34); also elsewhere on the board
AD_RX_FRA_N: U2.K1 (IO_L3N_T0_DQS_34); also elsewhere on the board
AD_RX_FRA_P: U2.K2 (IO_L3P_T0_DQS_34); also elsewhere on the board
AD_SPI_EN: U2.U7 (IO_L23P_T3_34); also elsewhere on the board
AD_SPI_MISO: U2.V6 (IO_L23N_T3_34); also elsewhere on the board
AD_SPI_MOSI: U2.K3 (IO_L4P_T0_34); also elsewhere on the board
AD_SPI_SCLK: U2.P6 (IO_L19P_T3_34); also elsewhere on the board
AD_SYNC_IN: U2.T5 (IO_L21N_T3_DQS_34); also elsewhere on the board
AD_TXNRX: U2.L5 (IO_L6P_T0_34); also elsewhere on the board
AD_TX_D0_N: U2.V4 (IO_L18N_T2_34); also elsewhere on the board
AD_TX_D0_P: U2.U4 (IO_L18P_T2_34); also elsewhere on the board
AD_TX_D1_N: U2.V2 (IO_L16N_T2_34); also elsewhere on the board
AD_TX_D1_P: U2.V3 (IO_L16P_T2_34); also elsewhere on the board
AD_TX_D2_N: U2.U5 (IO_L20N_T3_34); also elsewhere on the board
AD_TX_D2_P: U2.U6 (IO_L20P_T3_34); also elsewhere on the board
AD_TX_D3_N: U2.U1 (IO_L15N_T2_DQS_34); also elsewhere on the board
AD_TX_D3_P: U2.U2 (IO_L15P_T2_DQS_34); also elsewhere on the board
AD_TX_D4_N: U2.T2 (IO_L14N_T2_SRCC_34); also elsewhere on the board
AD_TX_D4_P: U2.R3 (IO_L14P_T2_SRCC_34); also elsewhere on the board
AD_TX_D5_N: U2.R1 (IO_L13N_T2_MRCC_34); also elsewhere on the board
AD_TX_D5_P: U2.R2 (IO_L13P_T2_MRCC_34); also elsewhere on the board
AD_TX_FRA_N: U2.T7 (IO_L22N_T3_34); also elsewhere on the board
AD_TX_FRA_P: U2.R7 (IO_L22P_T3_34); also elsewhere on the board
CLK: U2.C13 (IO_L11N_T1_SRCC_15); also elsewhere on the board
DONE_FPGA: R5.2, TP3.1 (1_1), U2.F12 (DONE_0); also elsewhere on the board
GND: C1.2, C2.2, C3.2, C4.2, C5.2, C6.2, C7.2, C8.2, C9.2, C10.2, C11.2, C12.2, C13.2, C14.2, C15.2, C16.2, C17.2, C18.2, C19.2, C20.2, C21.2, C22.2, C23.2, C24.2, C25.2, C26.2, C27.2, C28.2, C29.2, C30.2, C31.2, C32.2, C33.2, C34.2, C35.2, C36.2, C37.2, C42.2, C43.2, C44.2, C45.2, C46.2, C47.2, IC1.10 (VSS), J1.1, J1.5, R2(DNP)1.1, R4.1, R6.1, R21.1, U2.A1 (GND), U2.A3 (MGTPRXN1_216), U2.A4 (MGTPRXP1_216), U2.A5 (GND), U2.A7 (GND), U2.A8 (GND), U2.A11 (GND), U2.A18 (GND), U2.B3 (GND), U2.B7 (GND), U2.B8 (GND), U2.B18 (GND), U2.C2 (GND), U2.C3 (MGTPRXN2_216), U2.C4 (MGTPRXP2_216), U2.C6 (GND), U2.C7 (GND), U2.C15 (GND), U2.D3 (GND), U2.D4 (GND), U2.D7 (GND), U2.D12 (GND), U2.E2 (GND), U2.E6 (GND), U2.E7 (GND), U2.E9 (GND), U2.E12 (CFGBVS_0), U2.F4 (GND), U2.F6 (GND), U2.F10 (GND), U2.F16 (GND), U2.G1 (GND), U2.G3 (MGTPRXN3_216), U2.G4 (MGTPRXP3_216), U2.G5 (GND), U2.G6 (GND), U2.G7 (GND), U2.G9 (GND), U2.G11 (GND), U2.G13 (GND), U2.H3 (GND), U2.H4 (GND), U2.H5 (GND), U2.H6 (GND), U2.H8 (GND), U2.H10 (GND), U2.H12 (GND), U2.J1 (GND), U2.J2 (GND), U2.J3 (GND), U2.J7 (GND), U2.J9 (GNDADC_0), U2.J11 (GND), U2.J13 (GND), U2.J17 (GND), U2.K4 (GND), U2.K8 (GND), U2.K9 (VREFN_0), U2.K12 (GND), U2.K14 (GND), U2.L1 (GND), U2.L7 (GND), U2.L10 (VREFP_0), U2.L11 (GND), U2.L13 (GND), U2.M8 (GND), U2.M9 (DXN_0), U2.M10 (DXP_0), U2.M12 (GND), U2.M18 (GND), U2.N5 (GND), U2.N7 (GND), U2.N9 (GND), U2.N11 (GND), U2.N13 (GND), U2.N15 (GND), U2.P2 (GND), U2.P8 (GND), U2.P12 (GND), U2.R9 (GND), U2.T6 (GND), U2.T16 (GND), U2.U3 (GND), U2.U13 (GND), U2.V1 (GND), U2.V10 (GND), U2.V18 (GND), Y2.2 (GND); also elsewhere on the board
unnamed: GPIO5.1 (1_1), U2.U17 (IO_L16N_T2_A15_D31_14)
unnamed: GPIO2.1 (1_1), U2.U16 (IO_L17N_T2_A13_D29_14)
unnamed: GPIO1.1 (1_1), U2.U15 (IO_L17P_T2_A14_D30_14)
unnamed: GPIO4.1 (1_1), U2.V17 (IO_L18N_T2_A11_D27_14)
unnamed: GPIO3.1 (1_1), U2.V16 (IO_L18P_T2_A12_D28_14)
unnamed: C38.1, U2.H1 (MGTPTXN0_216)
unnamed: C39.1, U2.H2 (MGTPTXP0_216)
unnamed: R8.2, U2.A6 (MGTRREF_216)
OE: U2.B17 (IO_L16N_T2_A27_15); also elsewhere on the board
PCIE_CLK_N: U2.D5 (MGTREFCLK0N_216); also elsewhere on the board
PCIE_CLK_P: U2.D6 (MGTREFCLK0P_216); also elsewhere on the board
PCIE_RX_CM4_N: C38.2; also elsewhere on the board
PCIE_RX_CM4_P: C39.2; also elsewhere on the board
PCIE_TX_CM4_N: U2.E3 (MGTPRXN0_216); also elsewhere on the board
PCIE_TX_CM4_P: U2.E4 (MGTPRXP0_216); also elsewhere on the board
PCIE_nREQ: U2.C16 (IO_L16P_T2_A28_15); also elsewhere on the board
PCIE_nRST: U2.C17 (IO_L18P_T2_A24_15); also elsewhere on the board
RD: U2.A14 (IO_L8N_T1_AD10N_15); also elsewhere on the board
RESET: RESET1.1 (1_1), U2.J14 (IO_L5P_T0_D06_14)
RXF: U2.A12 (IO_L7N_T1_AD2N_15); also elsewhere on the board
SIWU: U2.B15 (IO_L9N_T1_DQS_AD3N_15); also elsewhere on the board
STAT_LED1: U2.B9 (IO_L3P_T0_DQS_AD1P_15); also elsewhere on the board
STAT_LED2: U2.B10 (IO_L5P_T0_AD9P_15); also elsewhere on the board
STAT_LED3: U2.A9 (IO_L3N_T0_DQS_AD1N_15); also elsewhere on the board
STAT_LED4: U2.A10 (IO_L5N_T0_AD9N_15); also elsewhere on the board
TXF: U2.A13 (IO_L8P_T1_AD10P_15); also elsewhere on the board
WR: U2.C14 (IO_L9P_T1_DQS_AD3P_15); also elsewhere on the board

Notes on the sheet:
VCCO34
Refer to UG470
VCCBRAM
POWER
FPGA CONFIG
FPGA CLOCK
PCIe
Refer to DS181
VCCO
VCCO
MGTVTT
for LVDS_25
Refer to UG482, CM4 Datasheet
VCCAUX
JTAG Header
MGTVCC
VCCINT
Pullups
VCCADC
Master SPI mode
FPGA I/O
POWER DECOUPLING
VCCO14
Refer to UG483, DS181
refer
SPI FLASH
VCCO15
VCCO_Bank0
Reference Docs

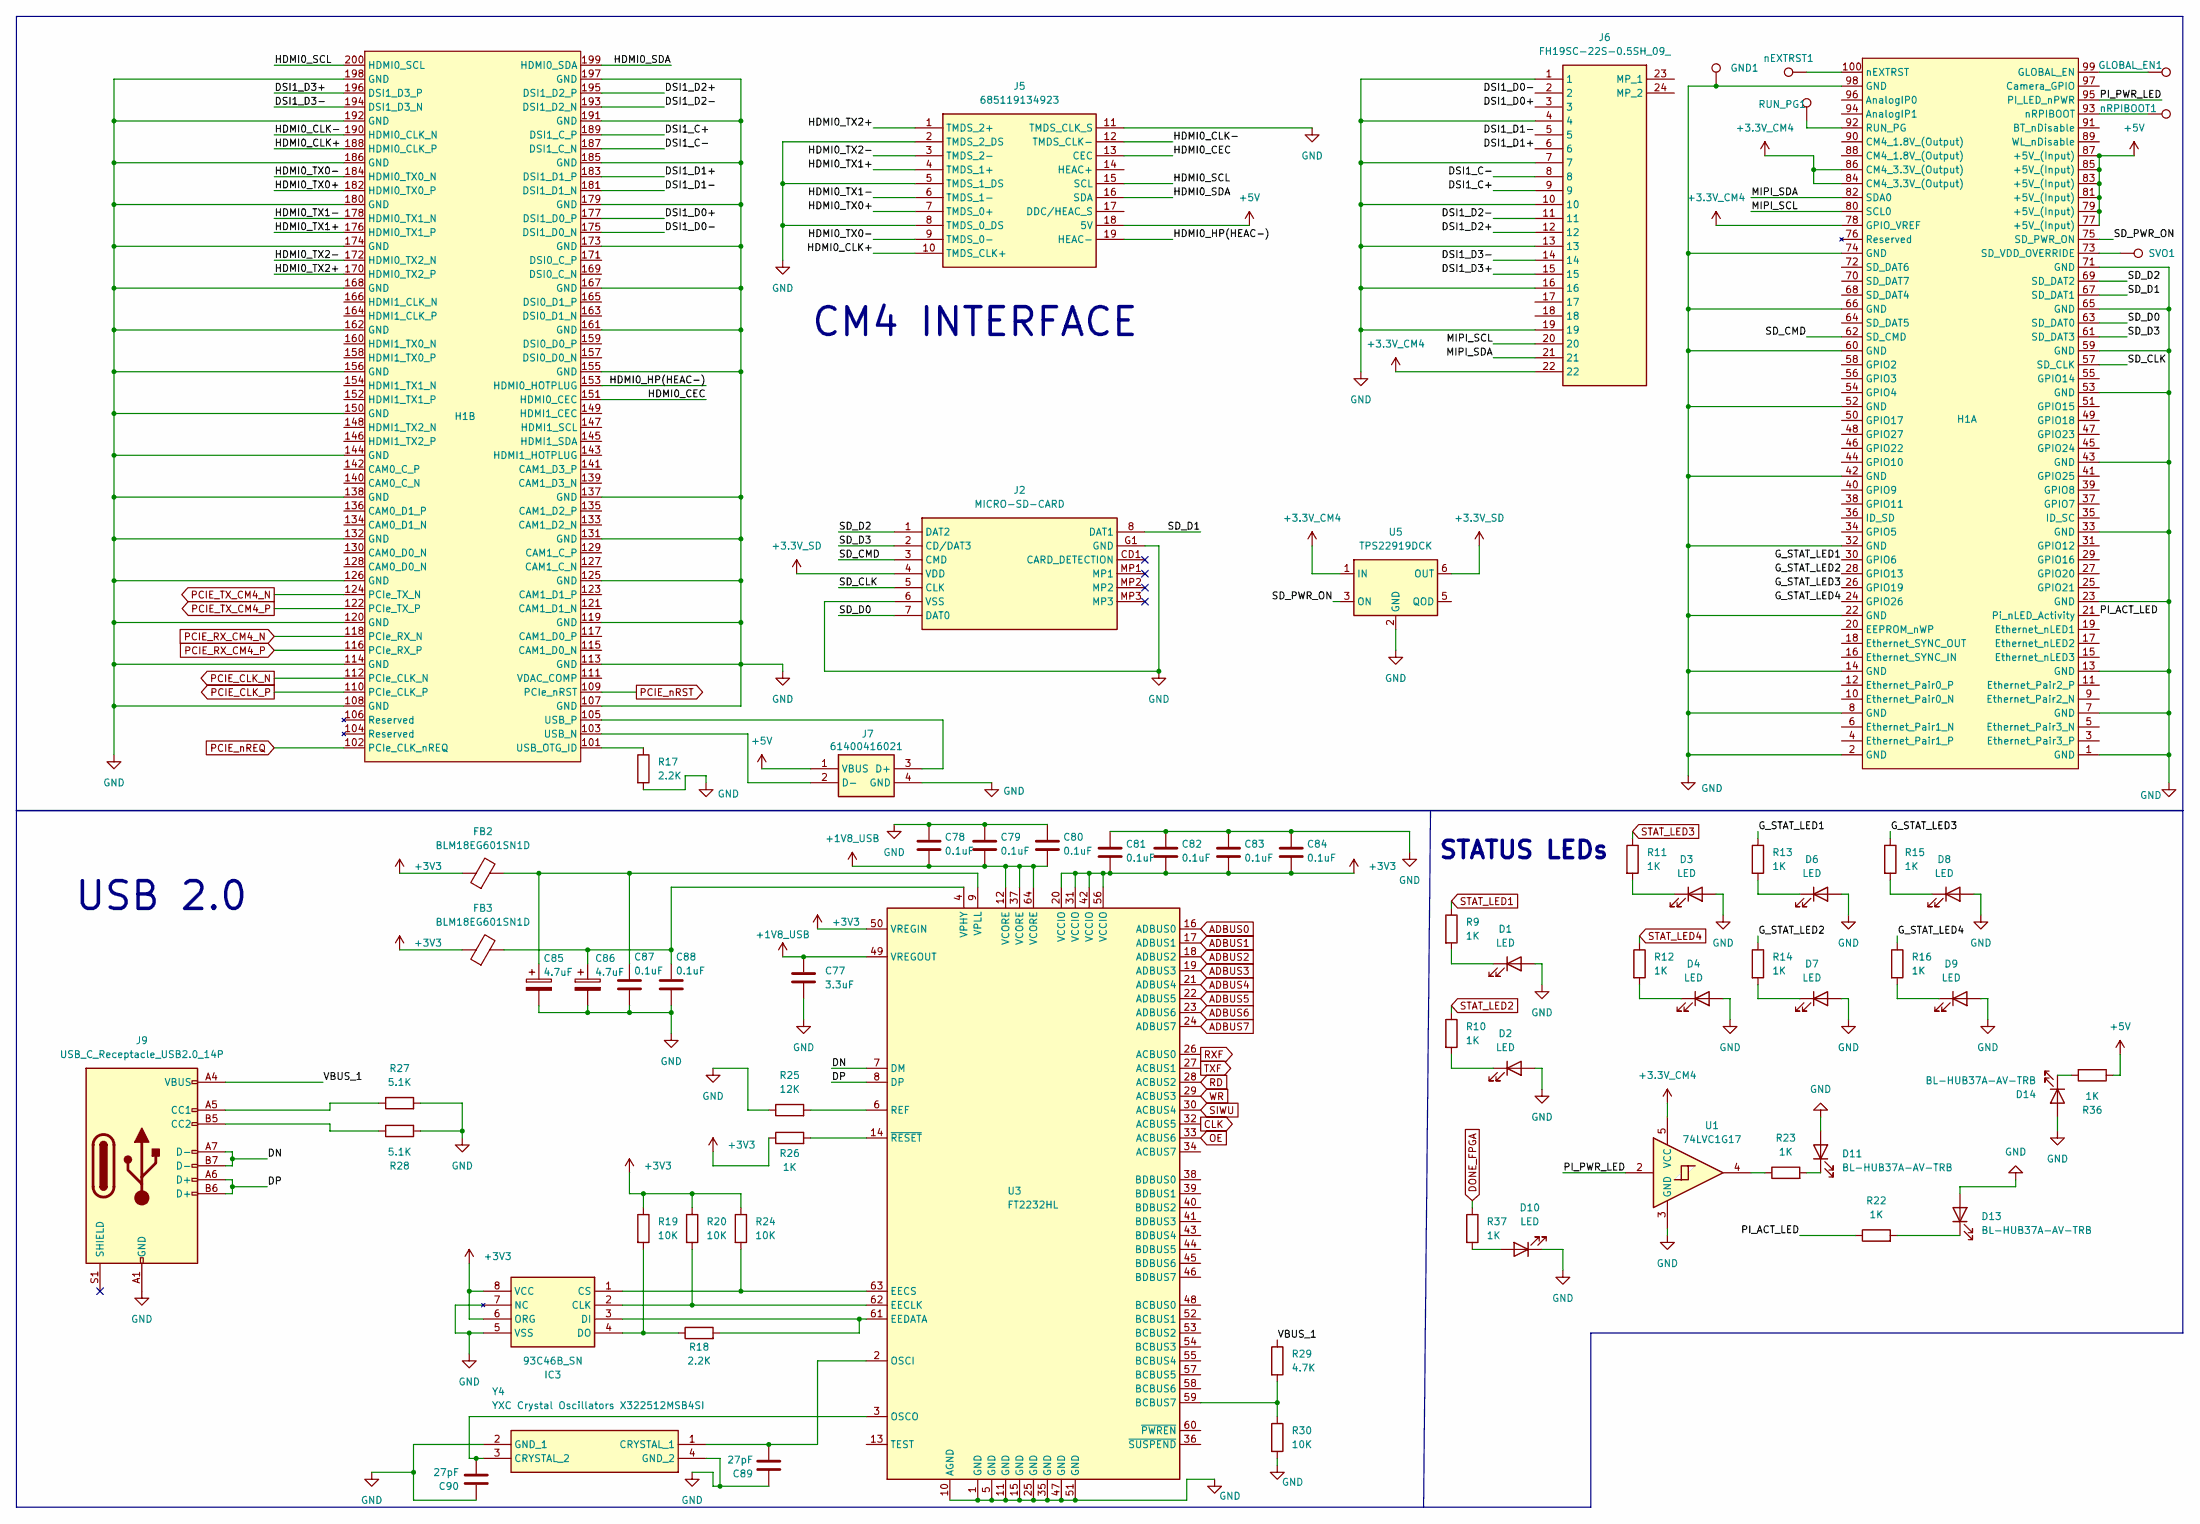
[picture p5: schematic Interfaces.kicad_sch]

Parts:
C77: 3.3uF; C_0603_1608Metric
C78, C79, C80, C81, C82, C83, C84, C87, C88: 0.1uF; C_0402_1005Metric
C85, C86: 4.7uF; C_0402_1005Metric
C89, C90: 27pF; C_0201_0603Metric
D1, D2, D3, D4, D6, D7, D8, D9, D10: LED; LED_0402_1005Metric
D11, D13, D14: BL-HUB37A-AV-TRB; LED_0402_1005Metric
FB2, FB3: BLM18EG601SN1D; L_0603_1608Metric
GLOBAL_EN1: TestPoint; TestPoint_Pad_1.0x1.0mm
GND1: TestPoint; TestPoint_Pad_1.0x1.0mm
H1: RaspberryPi-CM4-Module-Pad
IC3: 93C46B_SN; SOIC127P600X175-8N; Manufacturer_Part_Number 93C46B/SN; Mouser Part Number 579-93C46B/SN
J2: MICRO-SD-CARD; MICROSDCARD; Manufacturer_Part_Number MICRO-SD-CARD; Mouser Part Number N/A
J5: 685119134923; Mouser Part Number 710-685119134923
J6: FH19SC-22S-0.5SH_09_; FH19SC22S05SH09; Mouser Part Number 798-FH19SC22S05SH09
J7: 61400416021; USB-2.0-TYPE-A; Mouser Part Number 710-61400416021
J9: USB_C_Receptacle_USB2.0_14P; USB_C_Receptacle_JAE_DX07S016JA1R1500
R9, R10, R11, R12, R13, R14, R15, R16, R22, R23, R26, R36, R37: 1K; R_0402_1005Metric
R17, R18: 2.2K; R_0402_1005Metric
R19, R20, R24, R30: 10K; R_0402_1005Metric
R25: 12K; R_0402_1005Metric
R27, R28: 5.1K; R_0402_1005Metric
R29: 4.7K; R_0402_1005Metric
RUN_PG1: TestPoint; TestPoint_Pad_1.0x1.0mm
SVO1: TestPoint; TestPoint_Pad_1.0x1.0mm
U1: 74LVC1G17; SOT-23-5
U3: FT2232HL; LQFP-64_10x10mm_P0.5mm
U5: TPS22919DCK; SOT-363_SC-70-6
Y4: YXC Crystal Oscillators X322512MSB4SI; FA128400000MF20XK; Mouser Part Number 732-FA-12840MF20X-K
nEXTRST1: TestPoint; TestPoint_Pad_1.0x1.0mm
nRPIBOOT1: TestPoint; TestPoint_Pad_1.0x1.0mm

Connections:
+1V8_USB: C77.1, C78.2, C79.2, C80.2, U3.12 (VCORE), U3.37 (VCORE), U3.49 (VREGOUT), U3.64 (VCORE)
+3.3V_CM4: H1.78 (GPIO_VREF), H1.84 (CM4_3.3V_(Output)), H1.86 (CM4_3.3V_(Output)), J6.22, U1.5 (VCC), U5.1 (IN)
+3.3V_SD: J2.4 (VDD), U5.6 (OUT)
+3V3: C81.2, C82.2, C83.2, C84.2, FB2.1, FB3.1, IC3.6 (ORG), IC3.8 (VCC), R19.1, R20.1, R24.1, R26.1, U3.20 (VCCIO), U3.31 (VCCIO), U3.42 (VCCIO), U3.50 (VREGIN), U3.56 (VCCIO); also elsewhere on the board
+5V: H1.77 (+5V_(Input)), H1.79 (+5V_(Input)), H1.81 (+5V_(Input)), H1.83 (+5V_(Input)), H1.85 (+5V_(Input)), H1.87 (+5V_(Input)), J5.18 (5V), J7.1 (VBUS), R36.1; also elsewhere on the board
/Interfaces/DN: J9.A7 (D-), J9.B7 (D-), U3.7 (DM)
/Interfaces/DP: J9.A6 (D+), J9.B6 (D+), U3.8 (DP)
/Interfaces/DSI1_C+: H1.189 (DSI1_C_P), J6.9
/Interfaces/DSI1_C-: H1.187 (DSI1_C_N), J6.8
/Interfaces/DSI1_D0+: H1.177 (DSI1_D0_P), J6.3
/Interfaces/DSI1_D0-: H1.175 (DSI1_D0_N), J6.2
/Interfaces/DSI1_D1+: H1.183 (DSI1_D1_P), J6.6
/Interfaces/DSI1_D1-: H1.181 (DSI1_D1_N), J6.5
/Interfaces/DSI1_D2+: H1.195 (DSI1_D2_P), J6.12
/Interfaces/DSI1_D2-: H1.193 (DSI1_D2_N), J6.11
/Interfaces/DSI1_D3+: H1.196 (DSI1_D3_P), J6.15
/Interfaces/DSI1_D3-: H1.194 (DSI1_D3_N), J6.14
/Interfaces/G_STAT_LED1: H1.30 (GPIO6), R13.1
/Interfaces/G_STAT_LED2: H1.28 (GPIO13), R14.1
/Interfaces/G_STAT_LED3: H1.26 (GPIO19), R15.1
/Interfaces/G_STAT_LED4: H1.24 (GPIO26), R16.1
/Interfaces/HDMI0_CEC: H1.151 (HDMI0_CEC), J5.13 (CEC)
/Interfaces/HDMI0_CLK+: H1.188 (HDMI0_CLK_P), J5.10 (TMDS_CLK+)
/Interfaces/HDMI0_CLK-: H1.190 (HDMI0_CLK_N), J5.12 (TMDS_CLK-)
/Interfaces/HDMI0_HP(HEAC-): H1.153 (HDMI0_HOTPLUG), J5.19 (HEAC-)
/Interfaces/HDMI0_SCL: H1.200 (HDMI0_SCL), J5.15 (SCL)
/Interfaces/HDMI0_SDA: H1.199 (HDMI0_SDA), J5.16 (SDA)
/Interfaces/HDMI0_TX0+: H1.182 (HDMI0_TX0_P), J5.7 (TMDS_0+)
/Interfaces/HDMI0_TX0-: H1.184 (HDMI0_TX0_N), J5.9 (TMDS_0-)
/Interfaces/HDMI0_TX1+: H1.176 (HDMI0_TX1_P), J5.4 (TMDS_1+)
/Interfaces/HDMI0_TX1-: H1.178 (HDMI0_TX1_N), J5.6 (TMDS_1-)
/Interfaces/HDMI0_TX2+: H1.170 (HDMI0_TX2_P), J5.1 (TMDS_2+)
/Interfaces/HDMI0_TX2-: H1.172 (HDMI0_TX2_N), J5.3 (TMDS_2-)
/Interfaces/MIPI_SCL: H1.80 (SCL0), J6.20
/Interfaces/MIPI_SDA: H1.82 (SDA0), J6.21
/Interfaces/PI_ACT_LED: H1.21 (Pi_nLED_Activity), R22.1
/Interfaces/PI_PWR_LED: H1.95 (PI_LED_nPWR), U1.2
/Interfaces/SD_CLK: H1.57 (SD_CLK), J2.5 (CLK)
/Interfaces/SD_CMD: H1.62 (SD_CMD), J2.3 (CMD)
/Interfaces/SD_D0: H1.63 (SD_DAT0), J2.7 (DAT0)
/Interfaces/SD_D1: H1.67 (SD_DAT1), J2.8 (DAT1)
/Interfaces/SD_D2: H1.69 (SD_DAT2), J2.1 (DAT2)
/Interfaces/SD_D3: H1.61 (SD_DAT3), J2.2 (CD/DAT3)
/Interfaces/SD_PWR_ON: H1.75 (SD_PWR_ON), U5.3 (ON)
/Interfaces/VBUS_1: J9.A4 (VBUS), J9.A9 (VBUS), J9.B4 (VBUS), J9.B9 (VBUS), R29.1
ADBUS0: U3.16 (ADBUS0); also elsewhere on the board
ADBUS1: U3.17 (ADBUS1); also elsewhere on the board
ADBUS2: U3.18 (ADBUS2); also elsewhere on the board
ADBUS3: U3.19 (ADBUS3); also elsewhere on the board
ADBUS4: U3.21 (ADBUS4); also elsewhere on the board
ADBUS5: U3.22 (ADBUS5); also elsewhere on the board
ADBUS6: U3.23 (ADBUS6); also elsewhere on the board
ADBUS7: U3.24 (ADBUS7); also elsewhere on the board
CLK: U3.32 (ACBUS5); also elsewhere on the board
DONE_FPGA: R37.1; also elsewhere on the board
GND: C77.2, C78.1, C79.1, C80.1, C81.1, C82.1, C83.1, C84.1, C85.2, C86.2, C87.2, C88.2, C89.1, C90.1, D1.2 (A), D2.2 (A), D3.2 (A), D4.2 (A), D6.2 (A), D7.2 (A), D8.2 (A), D9.2 (A), D10.1 (K), D11.2 (A), D13.2 (A), D14.2 (A), GND1.1 (1_1), H1.1 (GND), H1.2 (GND), H1.7 (GND), H1.8 (GND), H1.13 (GND), H1.14 (GND), H1.22 (GND), H1.23 (GND), H1.32 (GND), H1.33 (GND), H1.42 (GND), H1.43 (GND), H1.52 (GND), H1.53 (GND), H1.59 (GND), H1.60 (GND), H1.65 (GND), H1.66 (GND), H1.71 (GND), H1.74 (GND), H1.98 (GND), H1.107 (GND), H1.108 (GND), H1.113 (GND), H1.114 (GND), H1.119 (GND), H1.120 (GND), H1.125 (GND), H1.126 (GND), H1.131 (GND), H1.132 (GND), H1.137 (GND), H1.138 (GND), H1.144 (GND), H1.150 (GND), H1.155 (GND), H1.156 (GND), H1.161 (GND), H1.162 (GND), H1.167 (GND), H1.168 (GND), H1.173 (GND), H1.174 (GND), H1.179 (GND), H1.180 (GND), H1.185 (GND), H1.186 (GND), H1.191 (GND), H1.192 (GND), H1.197 (GND), H1.198 (GND), IC3.5 (VSS), IC3.7 (NC), J2.6 (VSS), J2.G1 (GND), J5.2 (TMDS_2_DS), J5.5 (TMDS_1_DS), J5.8 (TMDS_0_DS), J5.11 (TMDS_CLK_S), J6.1, J6.4, J6.7, J6.10, J6.13, J6.16, J6.19, J7.4 (GND), J9.A1 (GND), J9.A12 (GND), J9.B1 (GND), J9.B12 (GND), R17.2, R25.1, R27.2, R28.2, R30.2, U1.3 (GND), U3.1 (GND), U3.5 (GND), U3.10 (AGND), U3.11 (GND), U3.15 (GND), U3.25 (GND), U3.35 (GND), U3.47 (GND), U3.51 (GND), U5.2 (GND), Y4.2 (GND_1), Y4.4 (GND_2); also elsewhere on the board
unnamed: D1.1 (K), R9.2
unnamed: D2.1 (K), R10.2
unnamed: D3.1 (K), R11.2
unnamed: D4.1 (K), R12.2
unnamed: D6.1 (K), R13.2
unnamed: D7.1 (K), R14.2
unnamed: D8.1 (K), R15.2
unnamed: D9.1 (K), R16.2
unnamed: D10.2 (A), R37.2
unnamed: D11.1 (K), R23.2
unnamed: D13.1 (K), R22.2
unnamed: D14.1 (K), R36.2
unnamed: GLOBAL_EN1.1 (1_1), H1.99 (GLOBAL_EN)
unnamed: H1.92 (RUN_PG), RUN_PG1.1 (1_1)
unnamed: H1.73 (SD_VDD_OVERRIDE), SVO1.1 (1_1)
unnamed: H1.100 (nEXTRST), nEXTRST1.1 (1_1)
unnamed: H1.93 (nRPIBOOT), nRPIBOOT1.1 (1_1)
unnamed: H1.103 (USB_N), J7.2 (D-)
unnamed: H1.101 (USB_OTG_ID), R17.1
unnamed: H1.105 (USB_P), J7.3 (D+)
unnamed: IC3.2 (CLK), R20.2, U3.62 (EECLK)
unnamed: IC3.1 (CS), R24.2, U3.63 (EECS)
unnamed: IC3.3 (DI), R18.2, U3.61 (EEDATA)
unnamed: IC3.4 (DO), R18.1, R19.2
unnamed: J9.A5 (CC1), R27.1
unnamed: J9.B5 (CC2), R28.1
unnamed: R23.1, U1.4
unnamed: R29.2, R30.1, U3.59 (BCBUS7)
unnamed: C89.2, U3.2 (OSCI), Y4.1 (CRYSTAL_1)
unnamed: C90.2, U3.3 (OSCO), Y4.3 (CRYSTAL_2)
unnamed: R25.2, U3.6 (REF)
unnamed: C86.1, C88.1, FB3.2, U3.4 (VPHY)
unnamed: C85.1, C87.1, FB2.2, U3.9 (VPLL)
unnamed: R26.2, U3.14 (~RESET)
OE: U3.33 (ACBUS6); also elsewhere on the board
PCIE_CLK_N: H1.112 (PCIe_CLK_N); also elsewhere on the board
PCIE_CLK_P: H1.110 (PCIe_CLK_P); also elsewhere on the board
PCIE_RX_CM4_N: H1.118 (PCIe_RX_N); also elsewhere on the board
PCIE_RX_CM4_P: H1.116 (PCIe_RX_P); also elsewhere on the board
PCIE_TX_CM4_N: H1.124 (PCIe_TX_N); also elsewhere on the board
PCIE_TX_CM4_P: H1.122 (PCIe_TX_P); also elsewhere on the board
PCIE_nREQ: H1.102 (PCIe_CLK_nREQ); also elsewhere on the board
PCIE_nRST: H1.109 (PCIe_nRST); also elsewhere on the board
RD: U3.28 (ACBUS2); also elsewhere on the board
RXF: U3.26 (ACBUS0); also elsewhere on the board
SIWU: U3.30 (ACBUS4); also elsewhere on the board
STAT_LED1: R9.1; also elsewhere on the board
STAT_LED2: R10.1; also elsewhere on the board
STAT_LED3: R11.1; also elsewhere on the board
STAT_LED4: R12.1; also elsewhere on the board
TXF: U3.27 (ACBUS1); also elsewhere on the board
WR: U3.29 (ACBUS3); also elsewhere on the board

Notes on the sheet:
CM4 INTERFACE
STATUS LEDs
USB 2.0

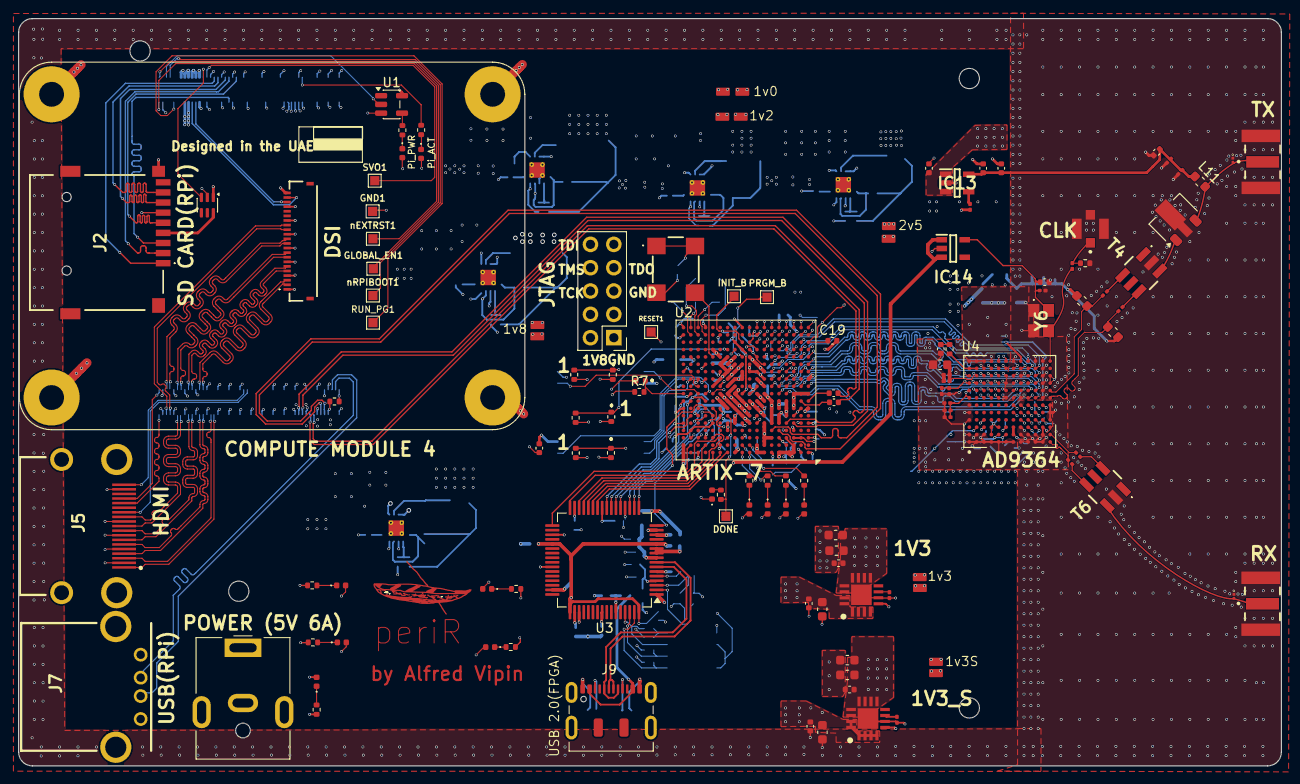
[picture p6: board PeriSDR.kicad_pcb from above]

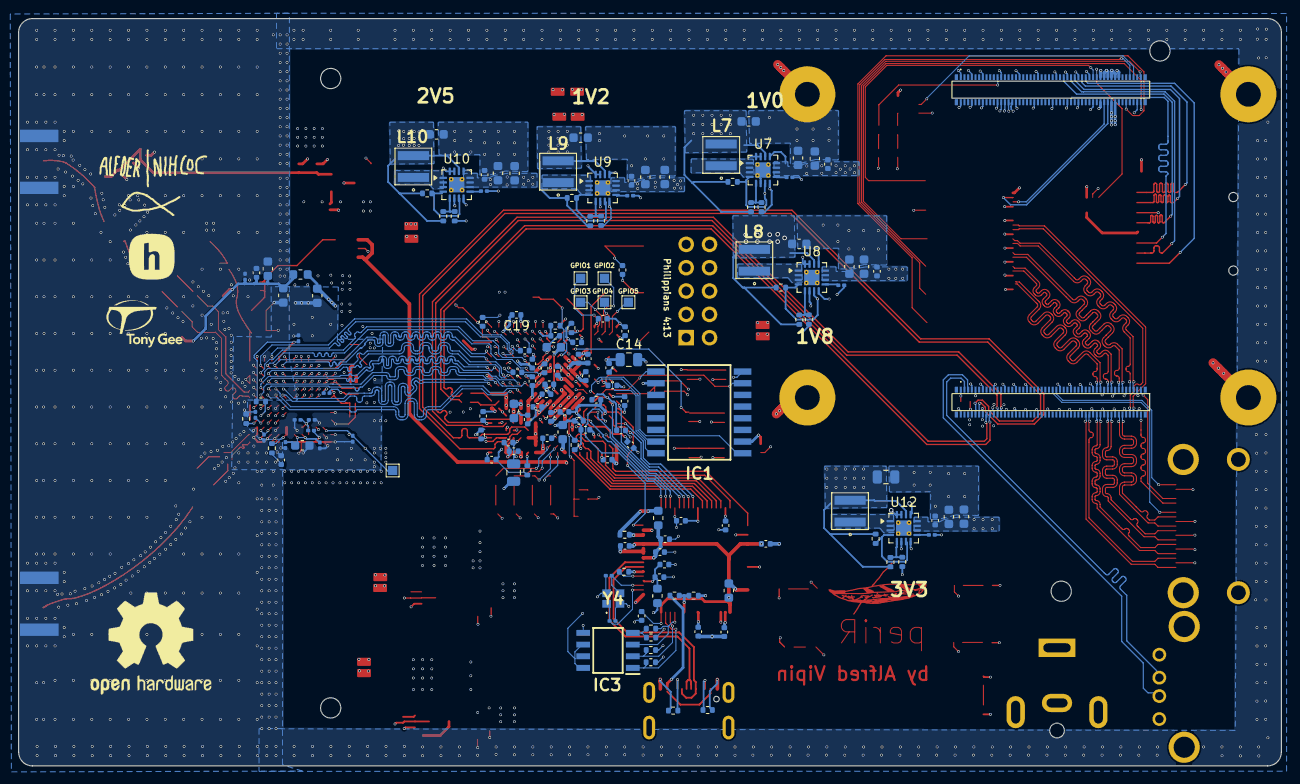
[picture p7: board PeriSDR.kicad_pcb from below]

Board: 6 copper layers, 137.4 x 81.3 mm, 266 parts (152 on the bottom side), 228 nets.

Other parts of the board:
C19#2: 4.7uF; C_0402_1005Metric

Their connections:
+2V5: C19#2.1; also elsewhere on the board
GND: C19#2.2; also elsewhere on the board

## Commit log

2026-06-23 Add periR_BOM.csv file
    [periR_BOM.csv]
2026-06-23 Add Bill of Materials section to README
    Added a Bill of Materials section with detailed component information including part numbers, manufacturers, quantities, and links.
2026-06-23 Add Bill of Materials section to README
2026-06-23 Add Compute Module 4 and PCB details to README
2026-06-23 Update total cost in Bill of Materials section
2026-06-27 Update total cost and change PCB to PCBA
2026-08-23 Delete HARDWARE directory
    Updated Files uploaded
    [Interfaces.kicad_sch, PeriSDR.kicad_pcb, PeriSDR.kicad_sch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]
2026-08-23 Updated Routing and Interfaces
    Added LEDs for headless troubleshooting and improved routing of high speed signals.
    [FPGA.kicad_sch, Interfaces.kicad_sch, PeriSDR.kicad_pcb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]
2026-09-14 Update DSI impedance to 100Ω Differential
2026-09-14 Update README with DEBUG LEDS and FPGA Interface details
    Added information about DEBUG LEDS and clarified FPGA Interface notes.
2026-09-14 Revise impedance details for LVDS signals in README
    Updated impedance information for layer 3 LVDS signals and noted the correction in the current PCB file.
2026-09-15 Add PeriR Non-Commercial Hardware License v1.0
    This license outlines the terms for using, modifying, and distributing the PeriR hardware and associated design materials for non-commercial purposes.
2026-09-16 Revise power plane description in README
    Clarified description of power plane issues in V2.
2026-09-17 Revise power plane description in README
